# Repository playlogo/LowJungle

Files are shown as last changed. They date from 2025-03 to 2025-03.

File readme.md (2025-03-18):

# LowJungle

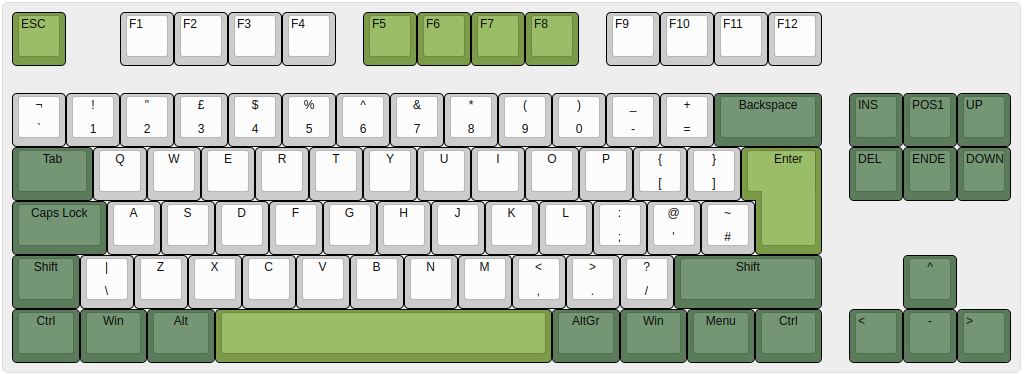
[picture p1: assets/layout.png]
Layout

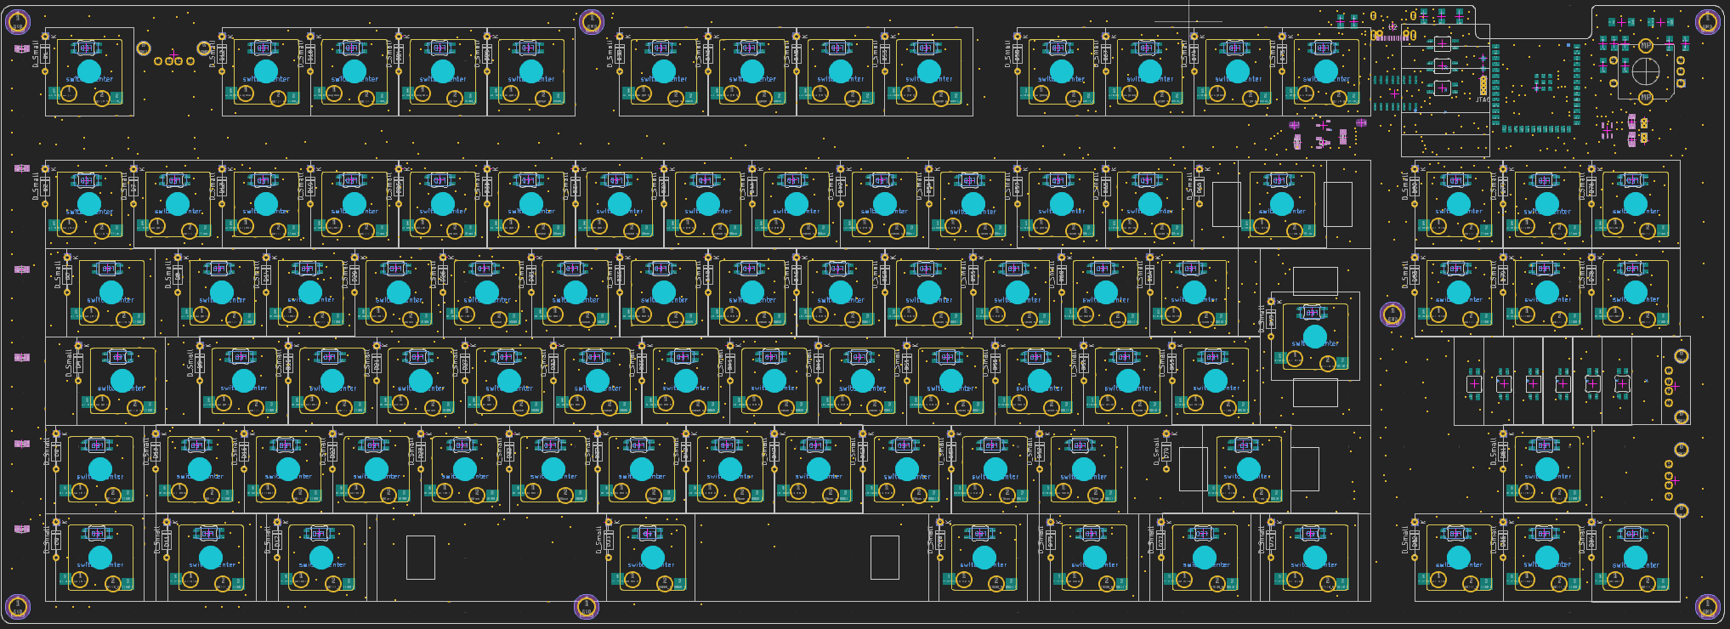
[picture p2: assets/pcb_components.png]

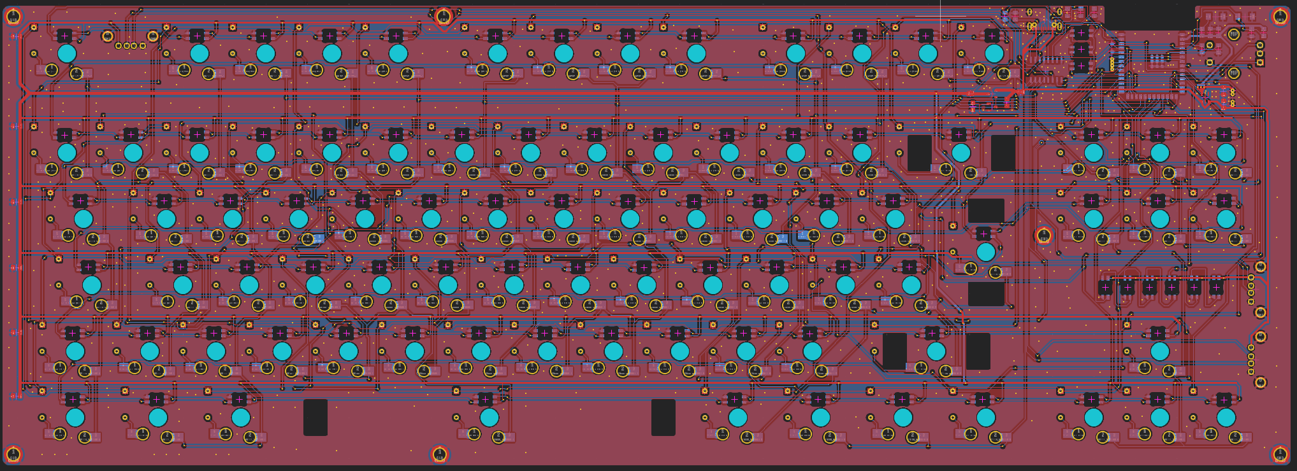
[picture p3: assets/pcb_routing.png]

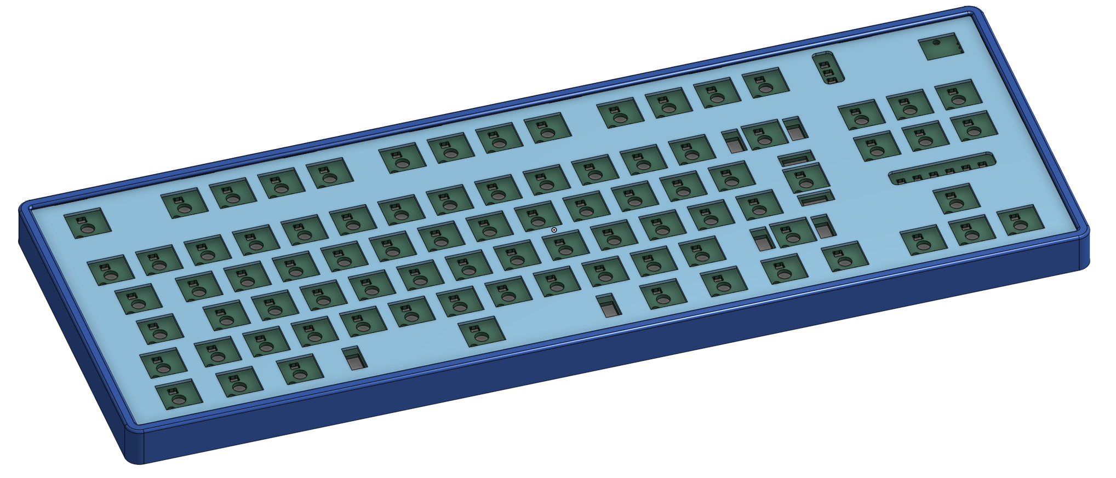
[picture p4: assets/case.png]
Case


A low profile, ~65% keyboard, with:

- Hot swappable sockets
- Per key RGB backlight
- Wifi & BLE (but no battery)
- Integrated 3 port USB Hub

Links:

- [Onshape: Case](https://cad.onshape.com/documents/196ae99135554e28081e9cd8/w/09114671e2d692aadc408c6f/e/86be969bd7a114ceaf756b4a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)
- [Keyboard Layout Editor: Layout](https://www.keyboard-layout-editor.com/#/gists/81105ca4efea79bf3cdf03d682872e17)

## Firmware

For testing: KMK  
For production: QMK

> Circuitpython is soooo much nicer for finding errors in the hardware  
> Status KMK: Pins are correct, keymap is WIP

## PCB

- [Schematic](assets/schematic.pdf)
- No relevant ERC & DRC errors
- Size: 371.48mm x 133.35mm
- VCC for backlight LEDs can be controlled by the ESP32 using 2 mosfets
- Used libraries:
  - [Marbastlib, needs to be installed as plugin](https://github.com/ebastler/marbastlib/tree/main)
  - [easyeda2kicad, needs to be installed separately, used for downloading LCSC schematics & footprints](https://github.com/uPesy/easyeda2kicad.py)
    - Download `C2913204, C192893, C2891732, C778164, C2988369, C8547, C503996, C82942` using `easyeda2kicad --full --lcsc_id=<id>` (one-by-one, yes...)
  - `0_Custom`, included in the `libraries` folder, should load automatically

## Fabrication

> I'm print all parts myself using [the large scale 3D printer (Billig)](https://github.com/playlogo/billig) I'm build for [infill](https://github.com/hackclub/infill).

> Download the latest revision from [Onshape](https://cad.onshape.com/documents/196ae99135554e28081e9cd8/w/09114671e2d692aadc408c6f/e/86be969bd7a114ceaf756b4a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). STLs included with this repo are only meant as a backup if the onshape link ever stops working.

- Largest part: 380mmx145mm
- Recommended settings:
  - 6 wall loops
  - 6 solid top & bottom layers
  - 40% infill
- Notes:
  - `LowJungle-Backplate-V2.stl`: Should be solid
  - `LowJungle-Bumper-Bottom-V2.stl`: Print with TPU, 3x
  - `LowJungle-Bumper-Top-V2.stl`: 4x
  - `LowJungle-Frame-V2.stl`: Manually place tree supports for the USB connector cutouts

## BOM

**PCB:** [$36.34 at JLCPCB](assets/jlcpcb.png)

**Switches:** [Aliexpress: Gateron KS33 low-profile red, 90 for $38.63 => 0.43 per switch](https://de.aliexpress.com/item/1005007794069535.html)

**Keycaps:** [Aliexpress: Low profile set, 143 lily version, $21.61](https://de.aliexpress.com/item/1005004882406296.html)

**Stabilizers:** [Aliexpress: Gateron low-profile stabilizer set, 4x 2u 1x 6.25u, $13.79](https://de.aliexpress.com/item/1005005296240590.html)

**Fasteners:**

| Name | Price | Link |
|---|---|---|
| 30x M2.5x3x3.5mm Heat insert | $1.83 | [Aliexpress](https://de.aliexpress.com/item/1005003582355741.html) |
| 14x M2.5x6mm Hex socket screw (for feet) | $1.41 | [Aliexpress](https://de.aliexpress.com/item/32810872544.html)|
| 16x M2.5x8mm Hex socket screw (for mounting frame) | $1.64 | [Aliexpress](https://de.aliexpress.com/item/32810872544.html) |
| 9x M3x10mm Hex socket screw | $1.79 | [Aliexpress](https://de.aliexpress.com/item/32810872544.html) |

Total: $6,67

**MCU:**

> Note: The ESP32S3 implementation is the same as in my [Hackpad](https://github.com/hackclub/hackpad/pull/570). Thus the cost can be drastically reduced when combining both LCSC orders:
>
> - -$3: Removed handling fee
> - -$6: Random shipping coupon
> - and often times the MOQ from hackpad also covers this project

|Name|Price|Link| Needed if combined order ? |
|----|-----|----|---|
|Espressif Systems ESP32-S3-WROOM-1-N8R2| $4.41| [LCSC](https://www.lcsc.com/product-detail/WiFi-Modules_Espressif-Systems-ESP32-S3-WROOM-1-N8R2_C2913204.html)| Yes|
| N-Channel mosfet | $0.6 for MOQ | [LCSC](https://www.lcsc.com/product-detail/MOSFETs_YONGYUTAI-SI2302_C2891732.html)| Yes |
|3.3V LDO | $0.48 for MOQ| [LCSC](https://www.lcsc.com/product-detail/Voltage-Regulators-Linear-Low-Drop-Out-LDO-Regulators_MICRONE-Nanjing-Micro-One-Elec-ME6211C33M5G-N_C82942.html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)| No |
| USB-A female| $0.42 for MOQ | [LCSC](https://www.lcsc.com/product-detail/USB-Connectors_Shenzhen-Kinghelm-Elec-KH-AF90DIP-112_C503996.html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)|No |
| USB-C female| $0.4 for MOQ | [LCSC](https://www.lcsc.com/product-detail/USB-Connectors_G-Switch-GT-USB-7010ASV_C2988369.html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)|No |
| P-Channel mosfet | $0.49 for MOQ | [LCSC](https://www.lcsc.com/product-detail/MOSFETs_Jiangsu-Changjing-Electronics-Technology-Co-Ltd-CJ2301-S1_C8547.html)|No |
| Mini push button | $0.47 for MOQ | [LCSC](https://www.lcsc.com/product-detail/Tactile-Switches_G-Switch-GT-TC029A-H020-L1N_C778164.html?s_z=n_SKRKAEE020)|No |
| CoreChips SL2.1A USB Hub driver | $1.32 for MOQ | [LCSC](https://www.lcsc.com/product-detail/USB-HUB-Controllers_CoreChips-SL2-1A_C192893.html?s_z=n_C192893)|No |
|---|----|---|---|
| 1N4148 Diodes | $1.04 for 100 | [LCSC](https://www.lcsc.com/product-detail/Switching-Diodes_LangJie-1N4148_C18195411.html?s_z=n_1N4148%2520Diodes) | Yes |
|10uF 0805 Capacitor | $0.16 for MOQ| [LCSC](https://www.lcsc.com/product-detail/Multilayer-Ceramic-Capacitors-MLCC-SMD-SMT_Samsung-Electro-Mechanics-CL21A106KOQNNNE_C1713.html)| No|
| 100nF * | $0.3 for MOQ | [LCSC](https://www.lcsc.com/product-detail/Multilayer-Ceramic-Capacitors-MLCC-SMD-SMT_FH-Guangdong-Fenghua-Advanced-Tech-0805B104J500NT_C29926.html)|No|
| 1uF * | $1 for MOQ | [LCSC](https://www.lcsc.com/product-detail/Multilayer-Ceramic-Capacitors-MLCC-SMD-SMT_YAGEO-CC0805JKX7R9BB105_C541528.html) | No |
|10k 0805 Resistor | $0.13 for MOQ | [LCSC](https://www.lcsc.com/product-detail/Chip-Resistor-Surface-Mount_VO-SCR0805J10K_C5140188.html?s_z=n_resistor)| No|
| 5.1k * | $0.15 for MOQ | [LCSC](https://www.lcsc.com/product-detail/Chip-Resistor-Surface-Mount_UNI-ROYAL-Uniroyal-Elec-0805W8J0512T5E_C26023.html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) | No |
| 100k * |  $0.13 for MOQ | [LCSC](https://www.lcsc.com/product-detail/Chip-Resistor-Surface-Mount_VO-SCR0805J100K_C3017875.html?s_z=n_resistor) | No |

Total (without combined order): $11.46  
Total (with combined order): $6.01

>Note: Combined LCSC order will be around ~$28 (including shipping) for both hackpad and hackboard

**Misc Electronics:**

|Name|Price|Link|
| ----- | ---- | ---- |
| SK6812 MINI-E | $2.85 for 100 | [Aliexpress](https://de.aliexpress.com/item/1005002782417198.html) |
| Gateron Low-profile hot-swap socket | $9.03 for 100 => $0.1 per socket | [Aliexpress](https://de.aliexpress.com/item/1005008078611488.html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) |
| Rotary-encoder | in stock | - |

Total: $11.88

**Other parts:**

|Name|Reason|Price|Link|
|----|---|-----|----|
| Poron foam, Bottom case <-> PCB, 2.5mm 15x35cm | Sound damping | $6.10 | [Aliexpress](https://de.aliexpress.com/item/1005007442653383.html)|
| EVA foam, PCB <-> Top plate , 1mm 35x50cm | Stability of top plate |  $2.05 | [Aliexpress](https://de.aliexpress.com/item/1005002856054113.html)|
|EVA foam, PCB <-> Keyswitch  | Sound damping | $3.42 | [Aliexpress](https://de.aliexpress.com/item/1005005556269716.html)|
|PE foam, Top plate <-> Keyswitch | Water spill protection (has happened before) | $2.19 | [Aliexpress](https://de.aliexpress.com/item/1005004804230184.html)|

Total: $13,76

### BOM total

**Fasteners:** $6,67
**PCB:** $36.34  
**Switches:** $38.63  
**Keycaps:** $21.61  
**Stabilizers:** $13.79  
**MCU:** $6.01  
**Misc Electronics:** $11.88  
**Other parts:** $13,76

**Total:** $148,69

> Note: Aliexpress prices are only valid until 26. March (15. anniversary sale)
> => If the grant is issued after 24. March, it would be awesome to have ~$15 buffer for changed prices. The unused amount would be returned to HackClub.

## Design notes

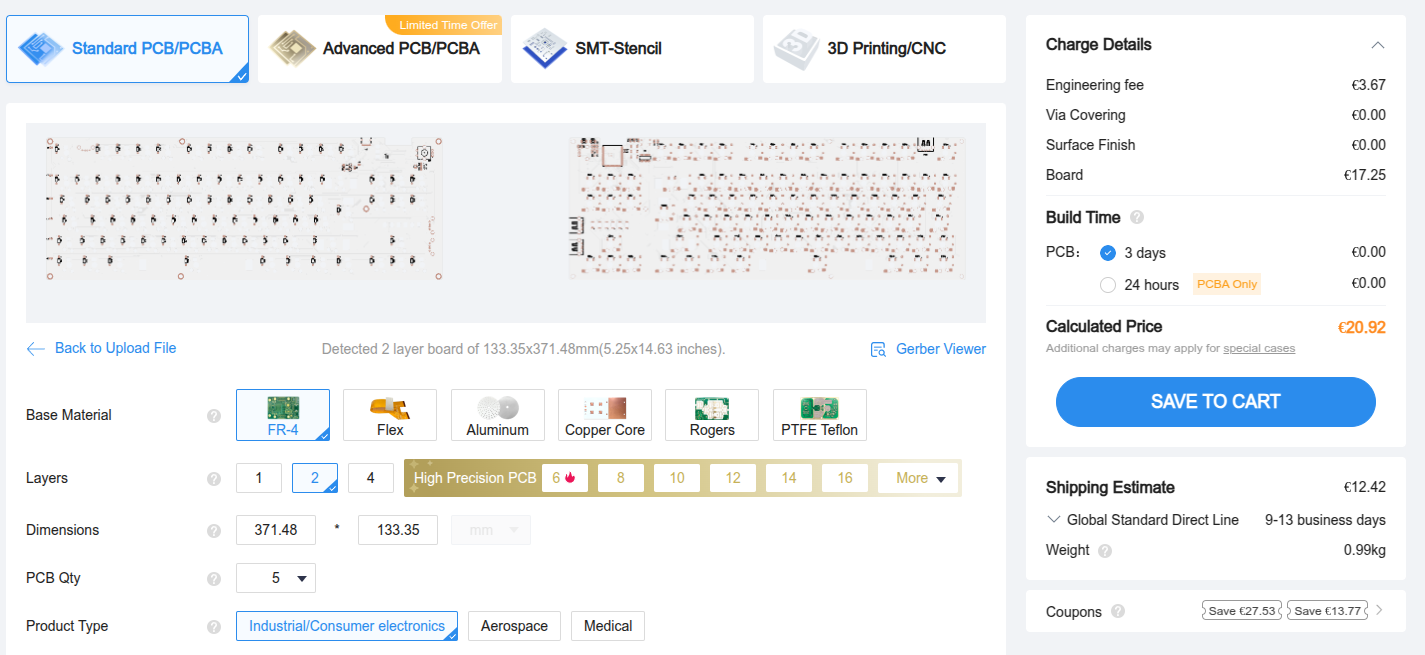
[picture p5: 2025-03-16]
assets/jlcpcb.png

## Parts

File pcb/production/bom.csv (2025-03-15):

Designator | Footprint | Quantity | Value | LCSC Part #
C1, C12, C13, C14, C2, C3, C4, C5, C6, C8 | 0805 | 10 | 10uF
C10, C11, C7 | 0805 | 3 | 100nF
C15, C16, C9 | 0805 | 3 | 1uF
CH1, CH10, CH12, CH13, CH14, CH15, CH16, CH18, CH19, CH2, CH20, CH21, CH22, CH24, CH25, CH26, CH27, CH28, CH29, CH30, CH31, CH32, CH33, CH34, CH35, CH36, CH37, CH38, CH39, CH40, CH41, CH42, CH43, CH44, CH45, CH46, CH47, CH48, CH49, CH50, CH51, CH52, CH53, CH54, CH55, CH56, CH57, CH58, CH59, CH60, CH61, CH62, CH63, CH64, CH65, CH67, CH7, CH74, CH75, CH76, CH77, CH78, CH79, CH8, CH80, CH81, CH82, CH83, CH84, CH85, CH9 | SW_KS33_HS_KS-2P02B01-02_1u | 71 | KS33_SW_HS
CH11, CH17, CH5, CH6, CH66, CH71, CH72, CH73 | SW_KS33_HS_KS-2P02B01-02_1.25u | 8 | KS33_SW_HS
CH23 | SW_KS33_HS_KS-2P02B01-02_6.25 | 1 | KS33_SW_HS
CH3 | SW_KS33_HS_KS-2P02B01-02_1.5u | 1 | KS33_SW_HS
CH4 | SW_KS33_HS_KS-2P02B01-02_1.75u | 1 | KS33_SW_HS
CH68 | SW_KS33_HS_KS-2P02B01-02_2u | 1 | KS33_SW_HS
CH69 | SW_KS33_HS_KS-2P02B01-02_Enter | 1 | KS33_SW_HS
CH70 | SW_KS33_HS_KS-2P02B01-02_2.75u | 1 | KS33_SW_HS
D1, D10, D11, D12, D13, D14, D15, D16, D17, D18, D19, D2, D20, D21, D22, D23, D24, D25, D26, D27, D28, D29, D3, D30, D31, D32, D33, D34, D35, D36, D37, D38, D39, D4, D40, D41, D42, D43, D44, D45, D46, D47, D48, D49, D5, D50, D51, D52, D53, D54, D55, D56, D57, D58, D59, D6, D60, D61, D62, D63, D64, D65, D66, D67, D68, D69, D7, D70, D71, D72, D73, D74, D75, D76, D77, D78, D79, D8, D80, D81, D82, D83, D84, D85, D9 | D_DO-35_SOD27_P7.62mm_Horizontal | 85 | D_Small
J1 | PinHeader_1x04_P1.00mm_Vertical | 1 | JTAG
J2 | PinHeader_1x02_P1.00mm_Vertical | 1 | 3.3V
J3 | PinHeader_1x02_P1.00mm_Vertical | 1 | 5V
LDO1 | SOT-23-5_L3.0-W1.7-P0.95-LS2.8-BL | 1 | ME6211C33M5G-N | C82942
LED1, LED10, LED11, LED12, LED13, LED14, LED15, LED16, LED17, LED18, LED19, LED2, LED20, LED21, LED22, LED23, LED24, LED25, LED26, LED27, LED28, LED29, LED3, LED30, LED31, LED32, LED33, LED34, LED35, LED36, LED37, LED38, LED39, LED4, LED40, LED41, LED42, LED43, LED44, LED45, LED46, LED47, LED48, LED49, LED5, LED50, LED51, LED52, LED53, LED54, LED55, LED56, LED57, LED58, LED59, LED6, LED60, LED61, LED62, LED63, LED64, LED65, LED66, LED67, LED68, LED69, LED7, LED70, LED71, LED72, LED73, LED74, LED75, LED76, LED77, LED78, LED79, LED8, LED80, LED81, LED82, LED83, LED84, LED85, LED86, LED87, LED88, LED89, LED9, LED90, LED91, LED92, LED93, LED94 | LED_KS33_6028R | 94 | KS33_SK6812MINI-E
Q1 | SOT-23-3_L3.0-W1.7-P0.95-LS2.9-BR | 1 | CJ2301 S1 | C8547
Q2 | SOT-23-3_L2.9-W1.3-P1.90-LS2.4-BR | 1 | SI2302_C2891732 | C2891732
R1, R2, R5 | 0805 | 3 | 10k
R3, R4, R6 | 0805 | 3 | 5.1k
SW1 | RotaryEncoder_Alps_EC11E-Switch_Vertical_H20mm_CircularMountingHoles | 1 | RotaryEncoder_Switch
SW2, SW3 | SW-SMD_L3.9-W2.9-LS5.0 | 2 | GT-TC029A-H020-L1N | C778164
TP1 | TestPoint_Pad_D1.0mm | 1 | RX
TP2 | TestPoint_Pad_D1.0mm | 1 | TX
U1 | WIRELM-SMD_ESP32-S3-WROOM-1 | 1 | ESP32-S3-WROOM-1(N8R2) | C2913204
U2 | USB-C-SMD_G-SWITCH_GT-USB-7010ASV | 1 | GT-USB-7010ASV | C2988369
U3 | SOP-16_L10.0-W3.9-P1.27-LS6.0-BL | 1 | SL2.1A | C192893
USB1, USB2 | USB-A-TH_USB-A-F-90 | 2 | KH-AF90DIP-112 | C503996
USB3 | USB-A-TH_USB-A-F-90 | 1 | DNP | C503996

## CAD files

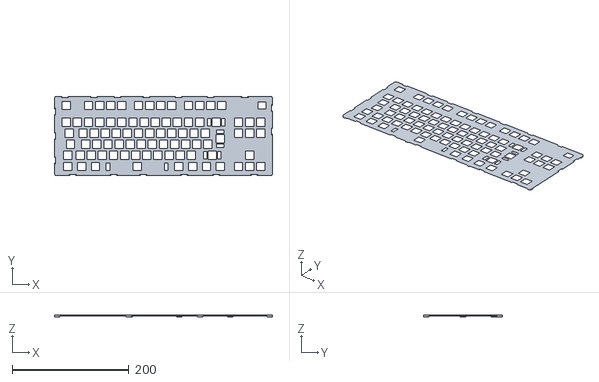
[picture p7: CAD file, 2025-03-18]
case/LowJungle-Backplate-V2.stl
373.9 x 135.8 x 2.59

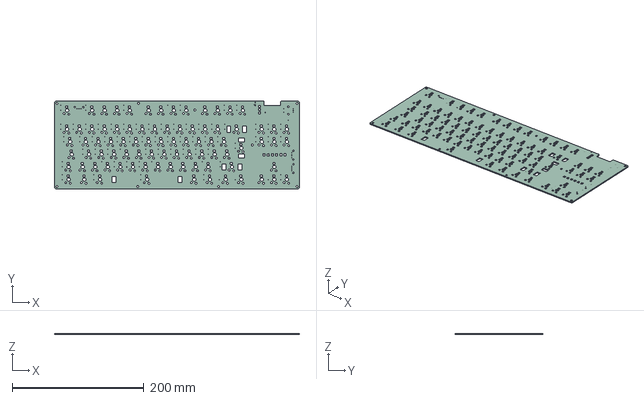
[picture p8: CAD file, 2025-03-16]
pcb/LowJungle.step
371.5 x 133.4 x 1.51 mm
LowJungle_copper
LowJungle_PCB

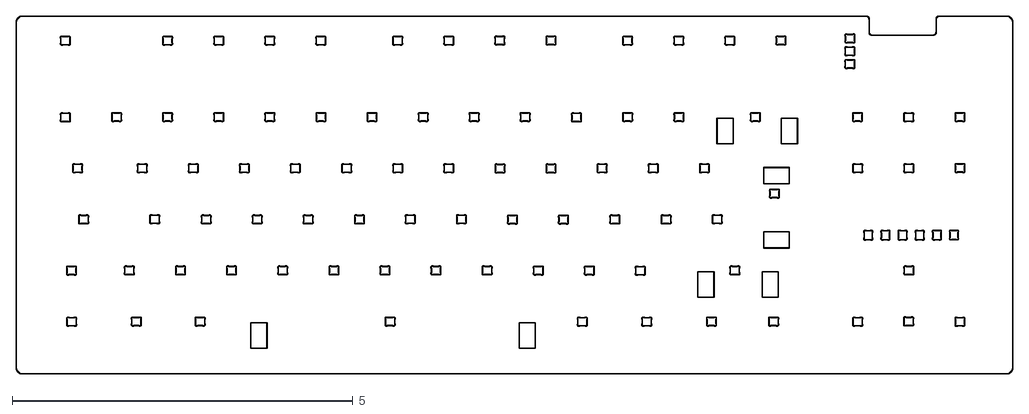
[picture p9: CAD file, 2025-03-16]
pcb/out/LowJungle-Edge_Cuts.dxf
14.6 x 5.25

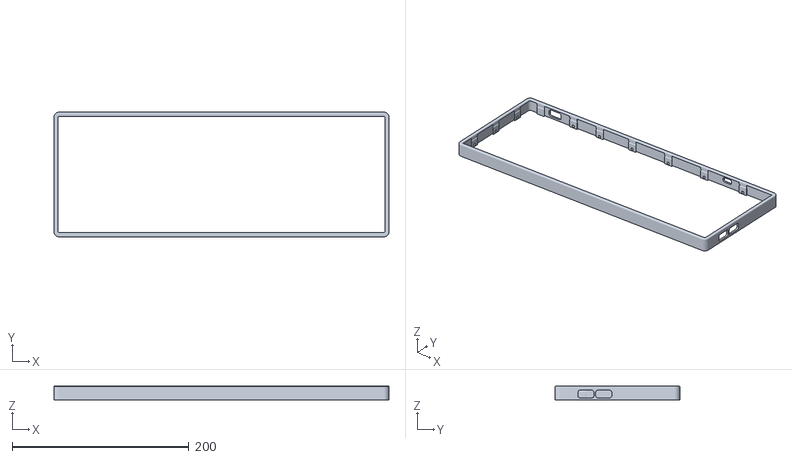
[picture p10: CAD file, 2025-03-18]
case/LowJungle-Frame-V2.stl
379.3 x 141.2 x 16.2

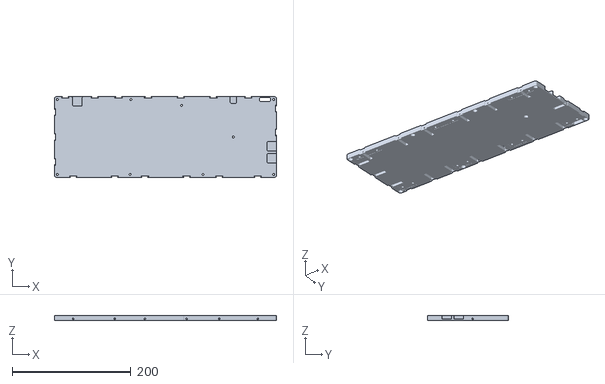
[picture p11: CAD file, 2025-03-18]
case/LowJungle-Bottom-V2.stl
373.9 x 135.8 x 8.00

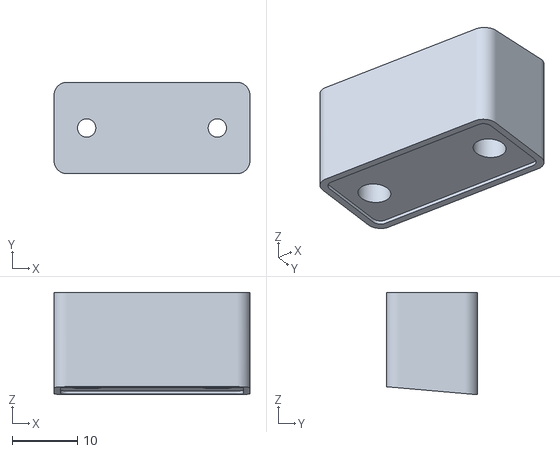
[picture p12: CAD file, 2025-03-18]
case/LowJungle-Bumper-Top-V2.stl
30.0 x 14.0 x 15.7

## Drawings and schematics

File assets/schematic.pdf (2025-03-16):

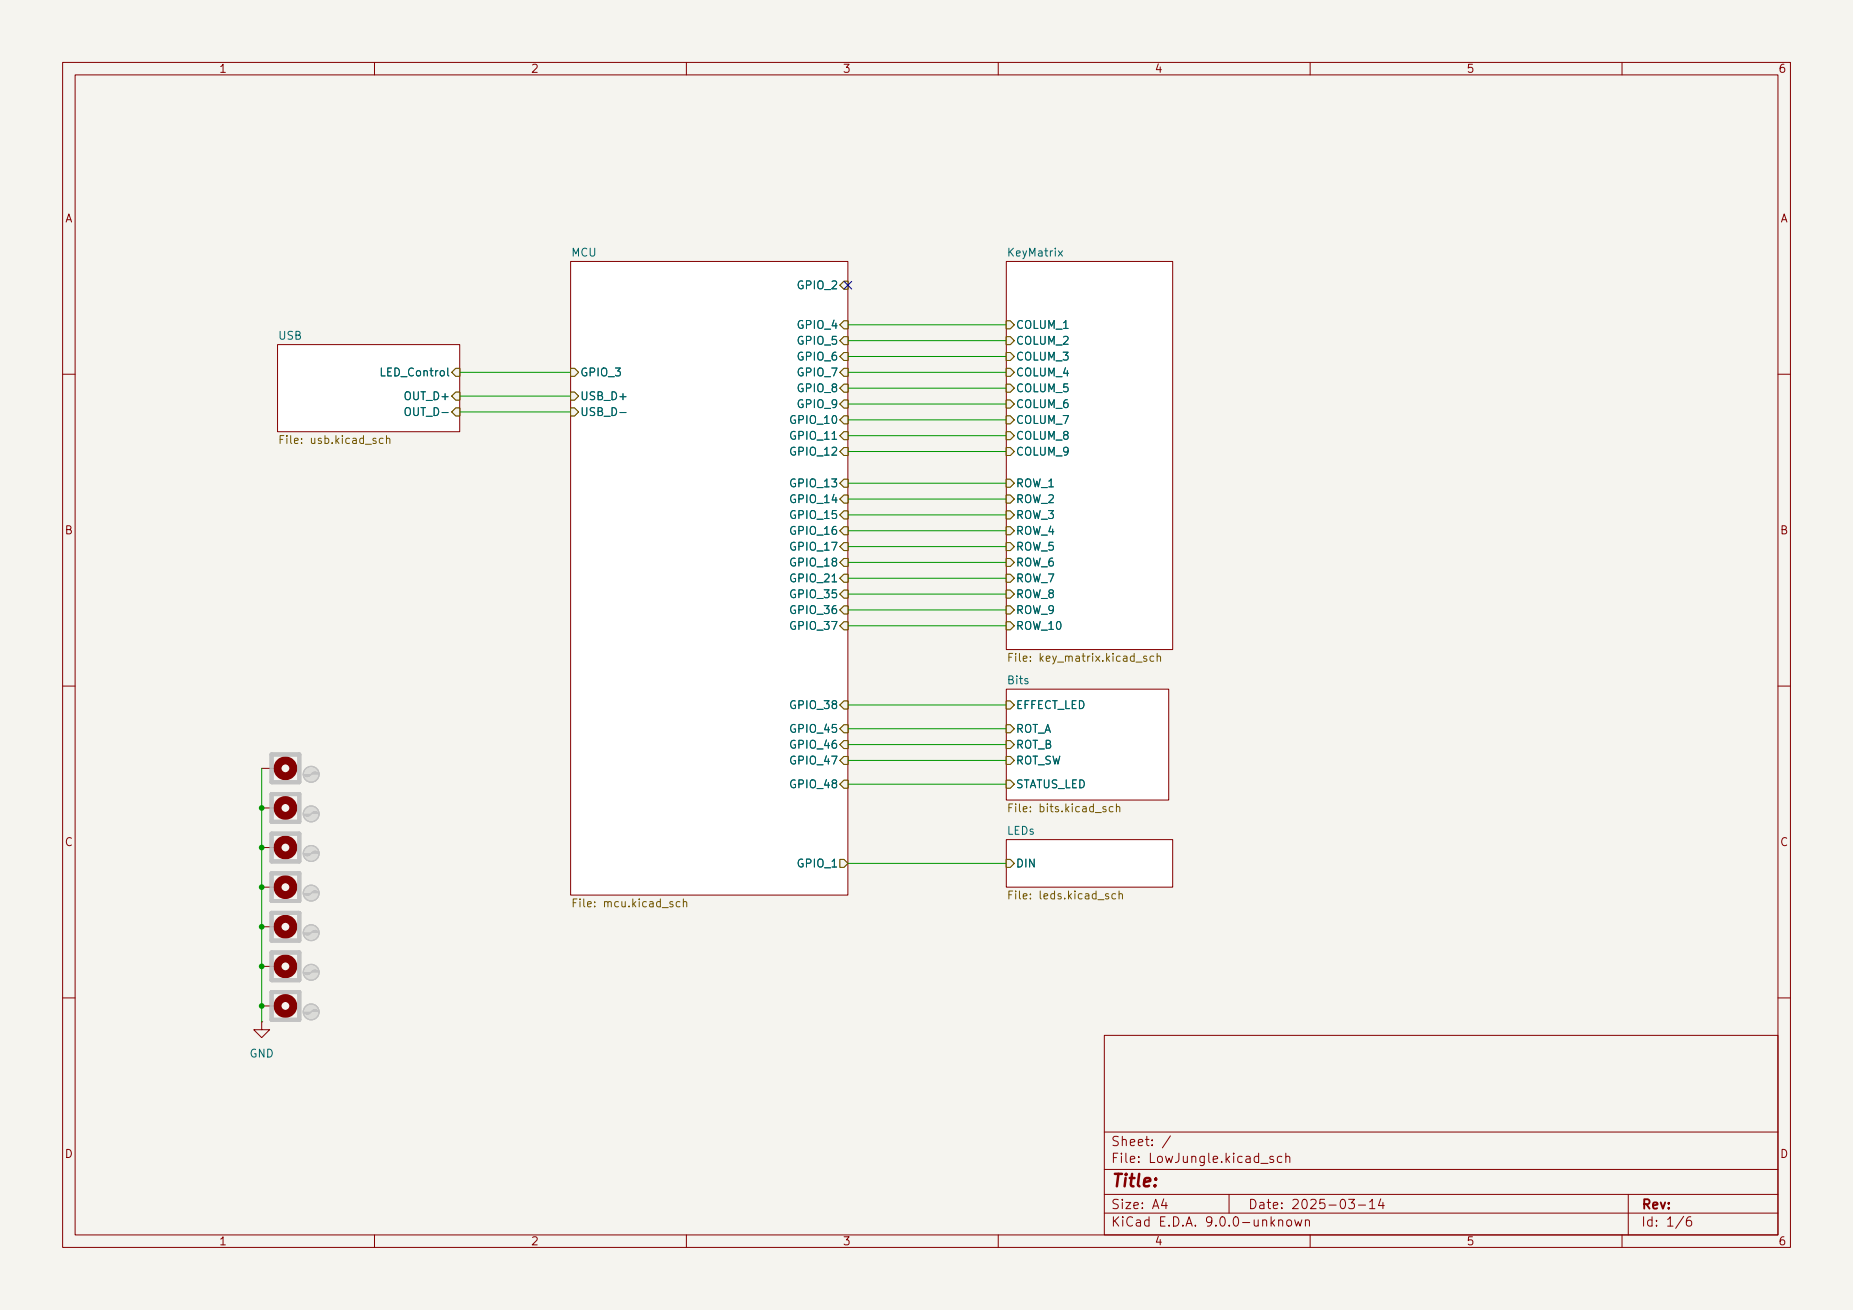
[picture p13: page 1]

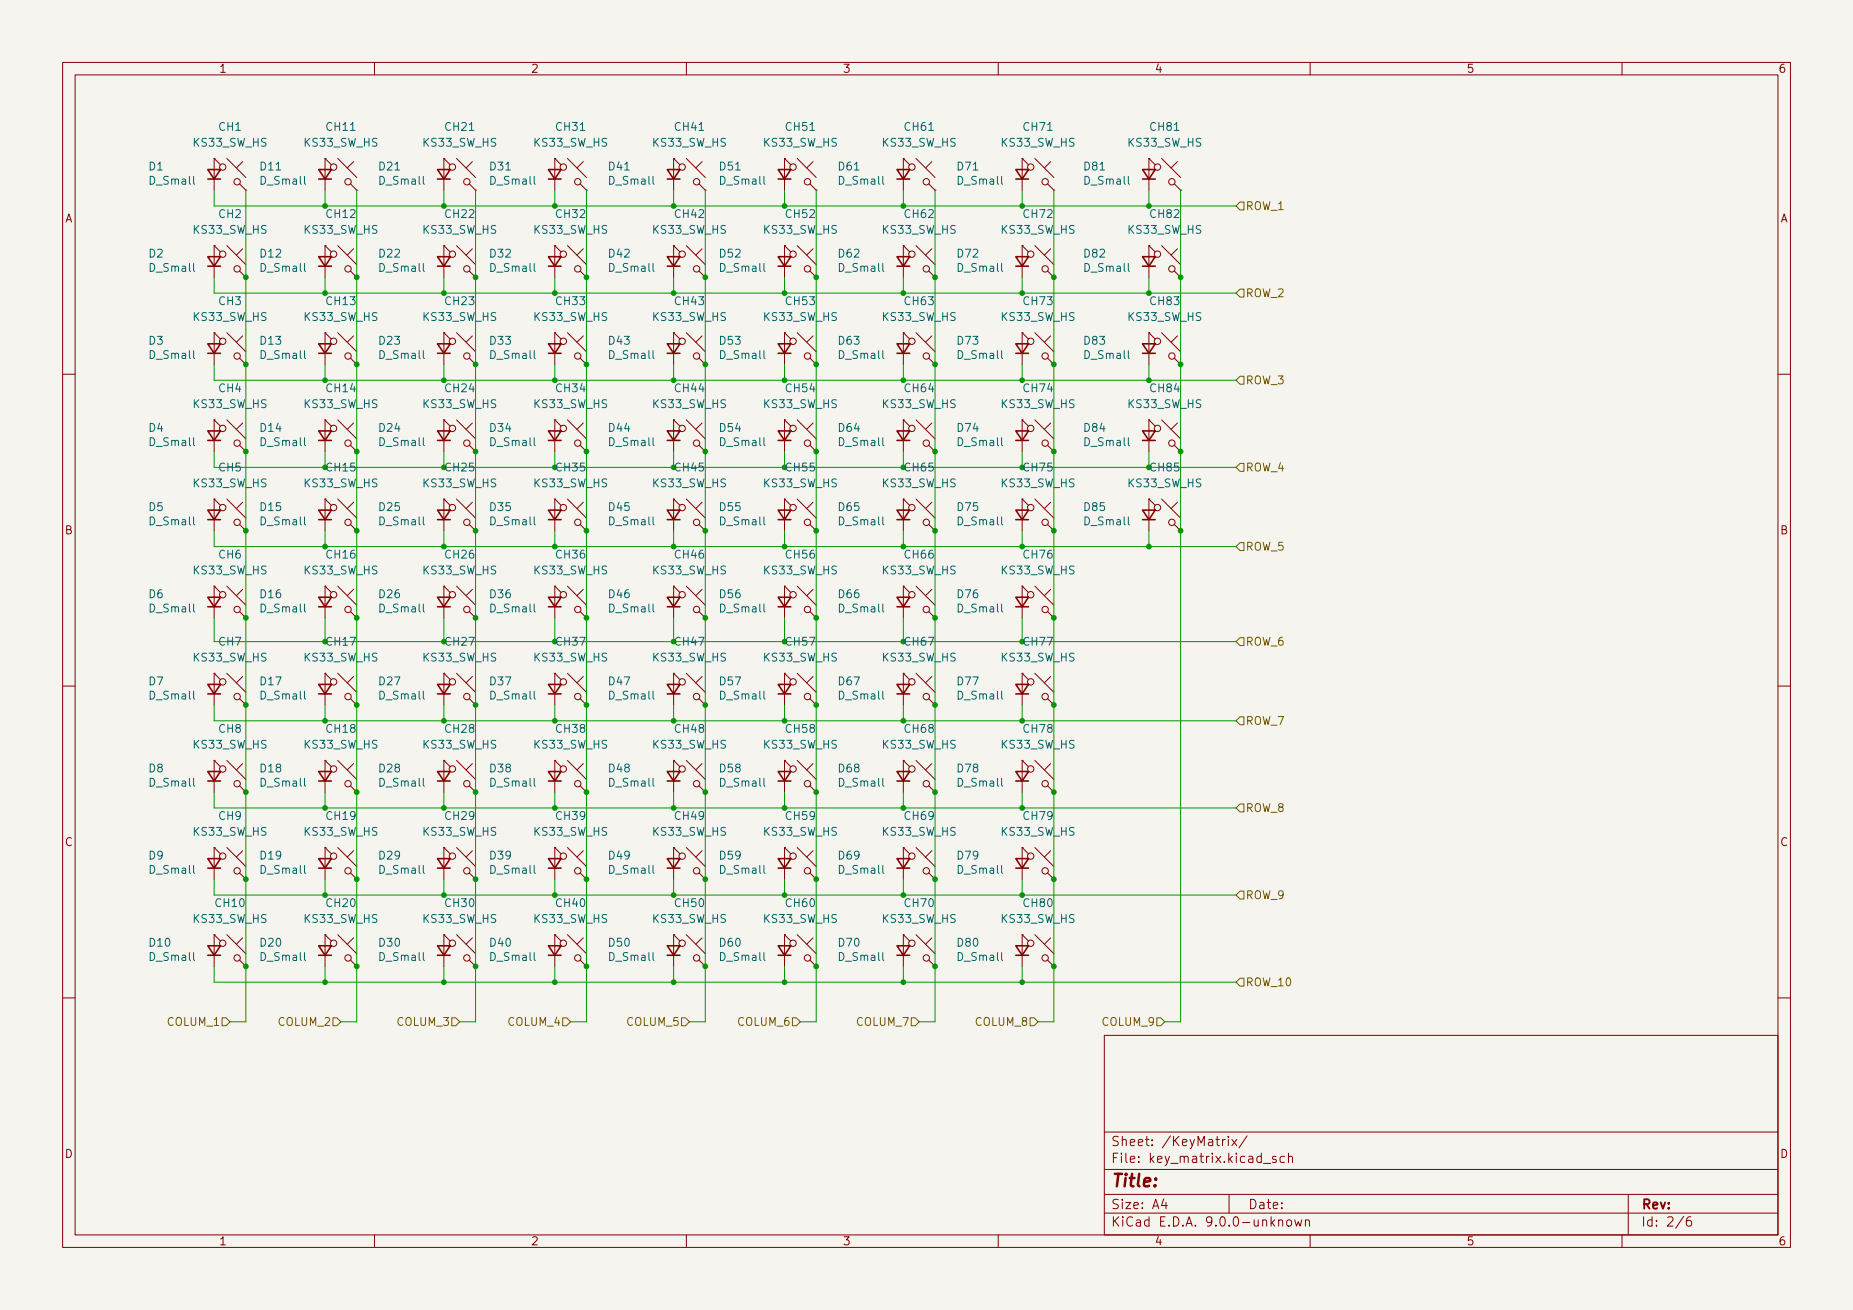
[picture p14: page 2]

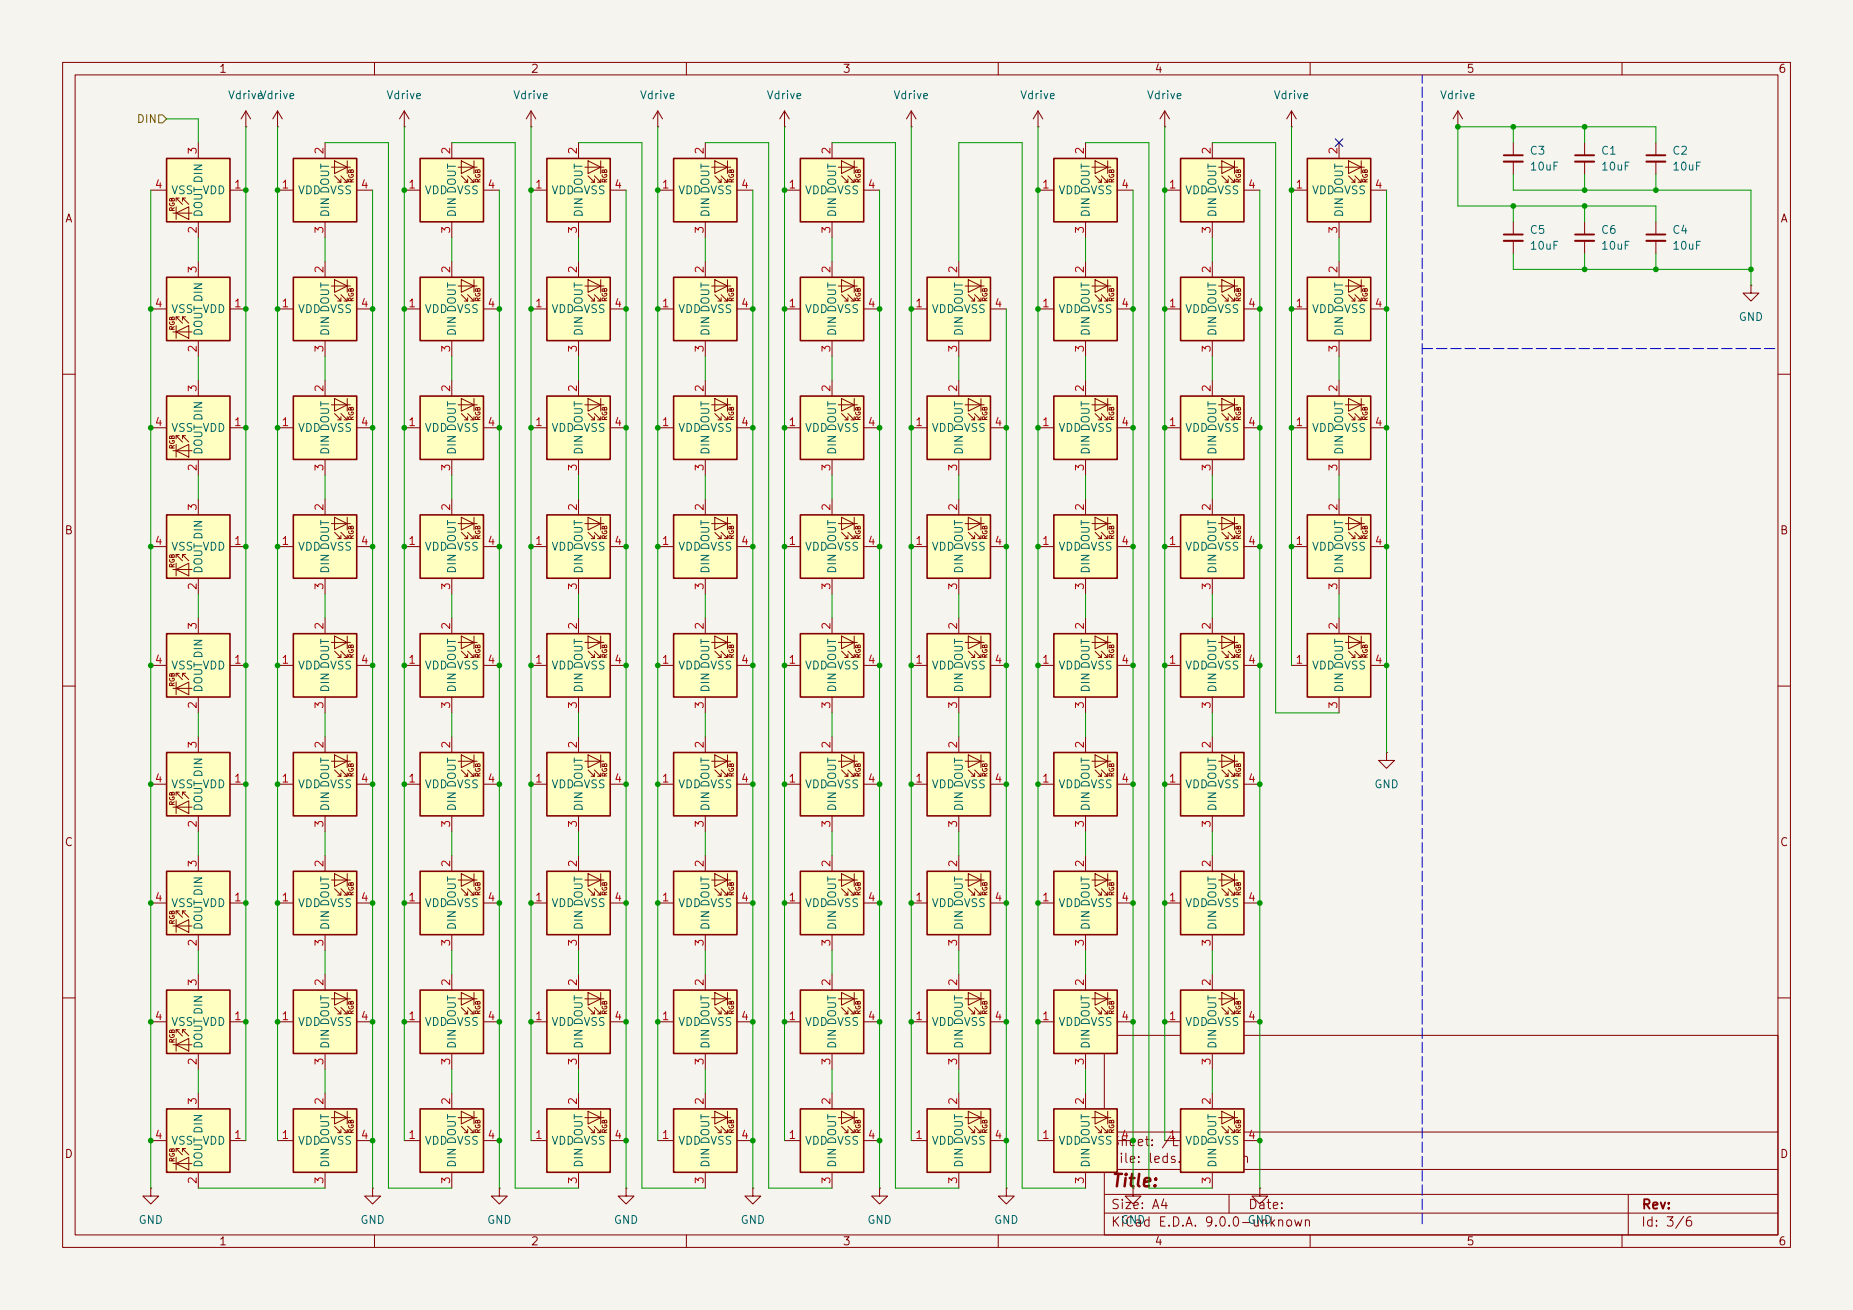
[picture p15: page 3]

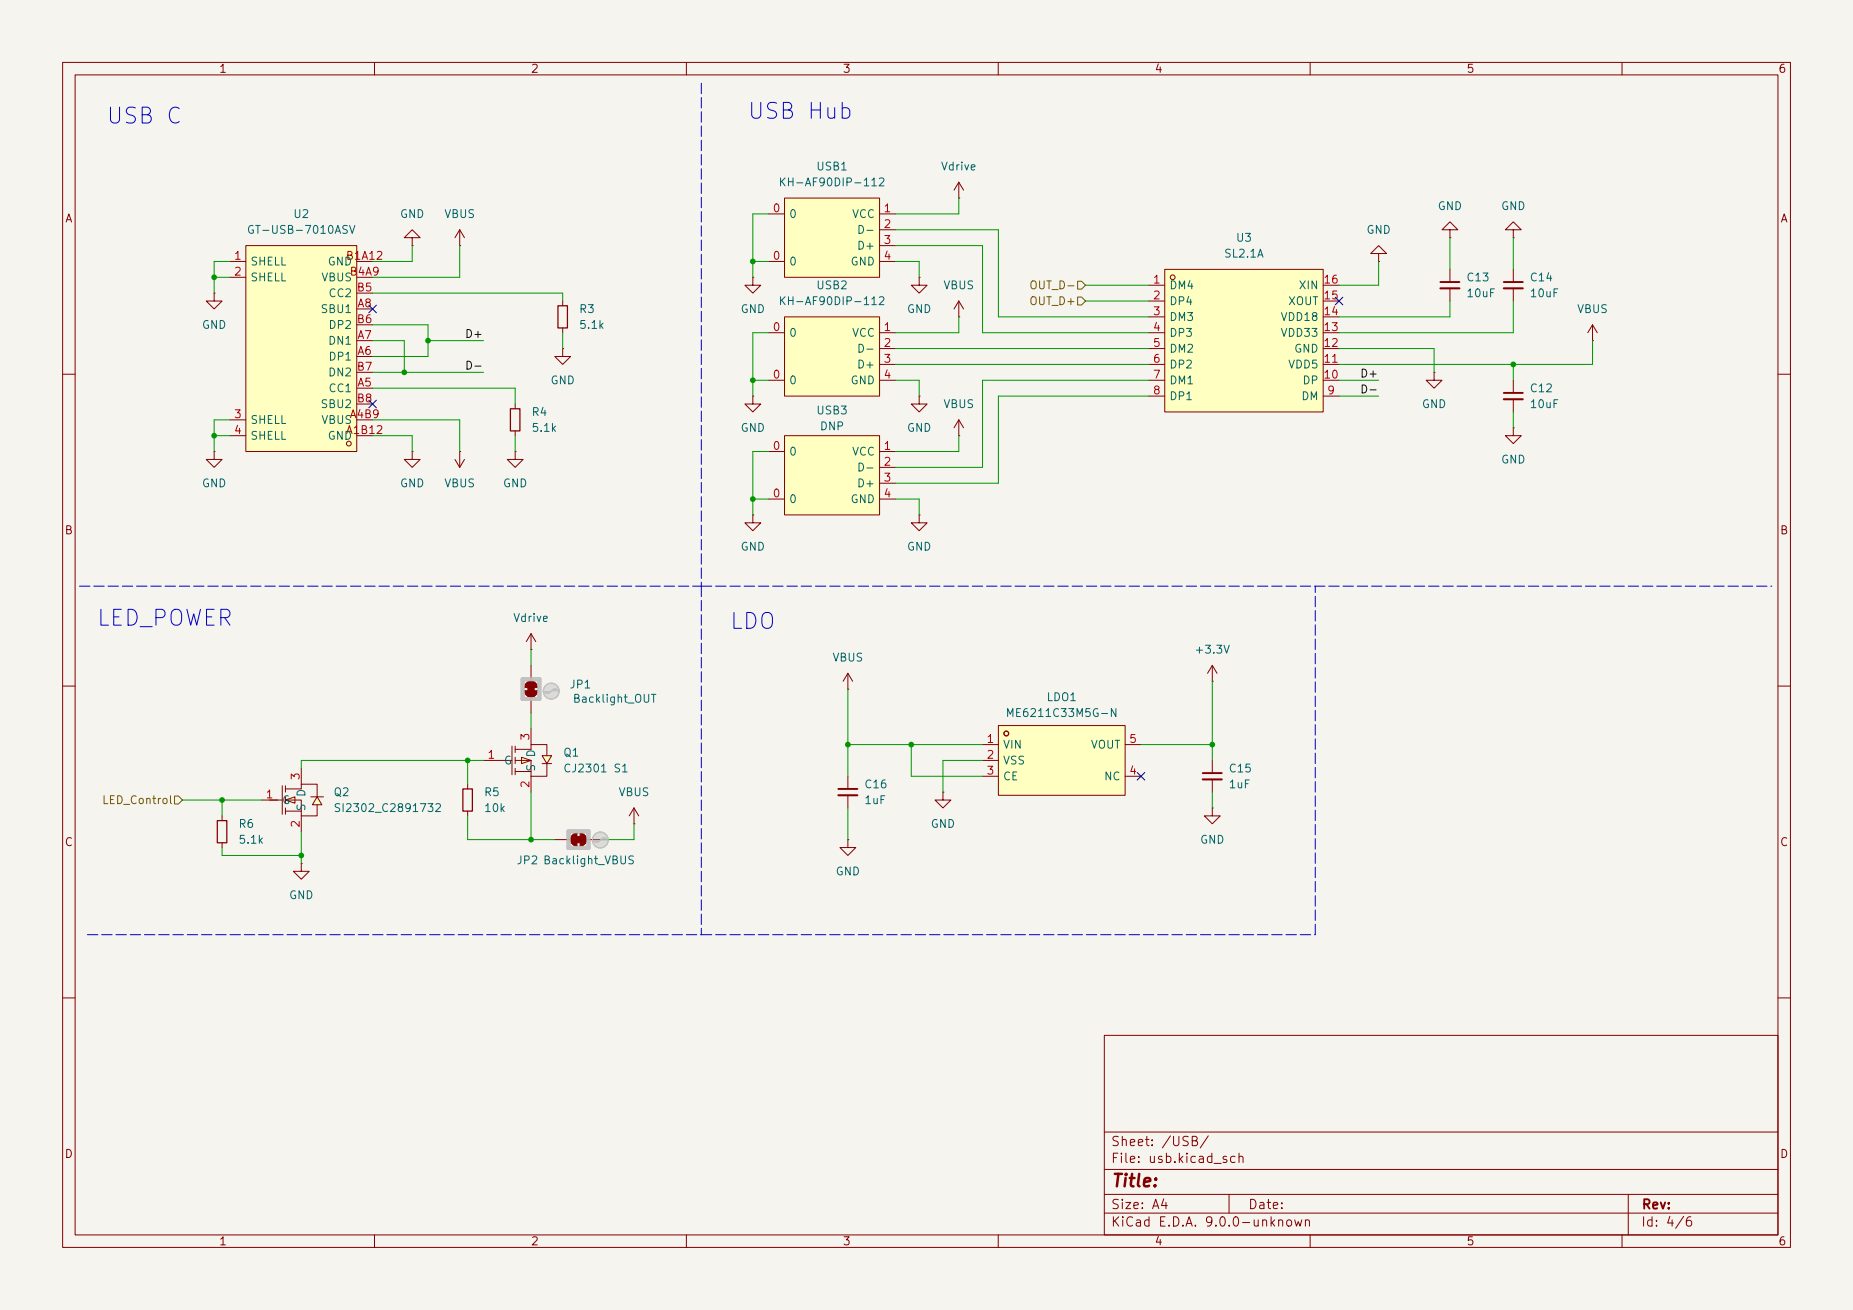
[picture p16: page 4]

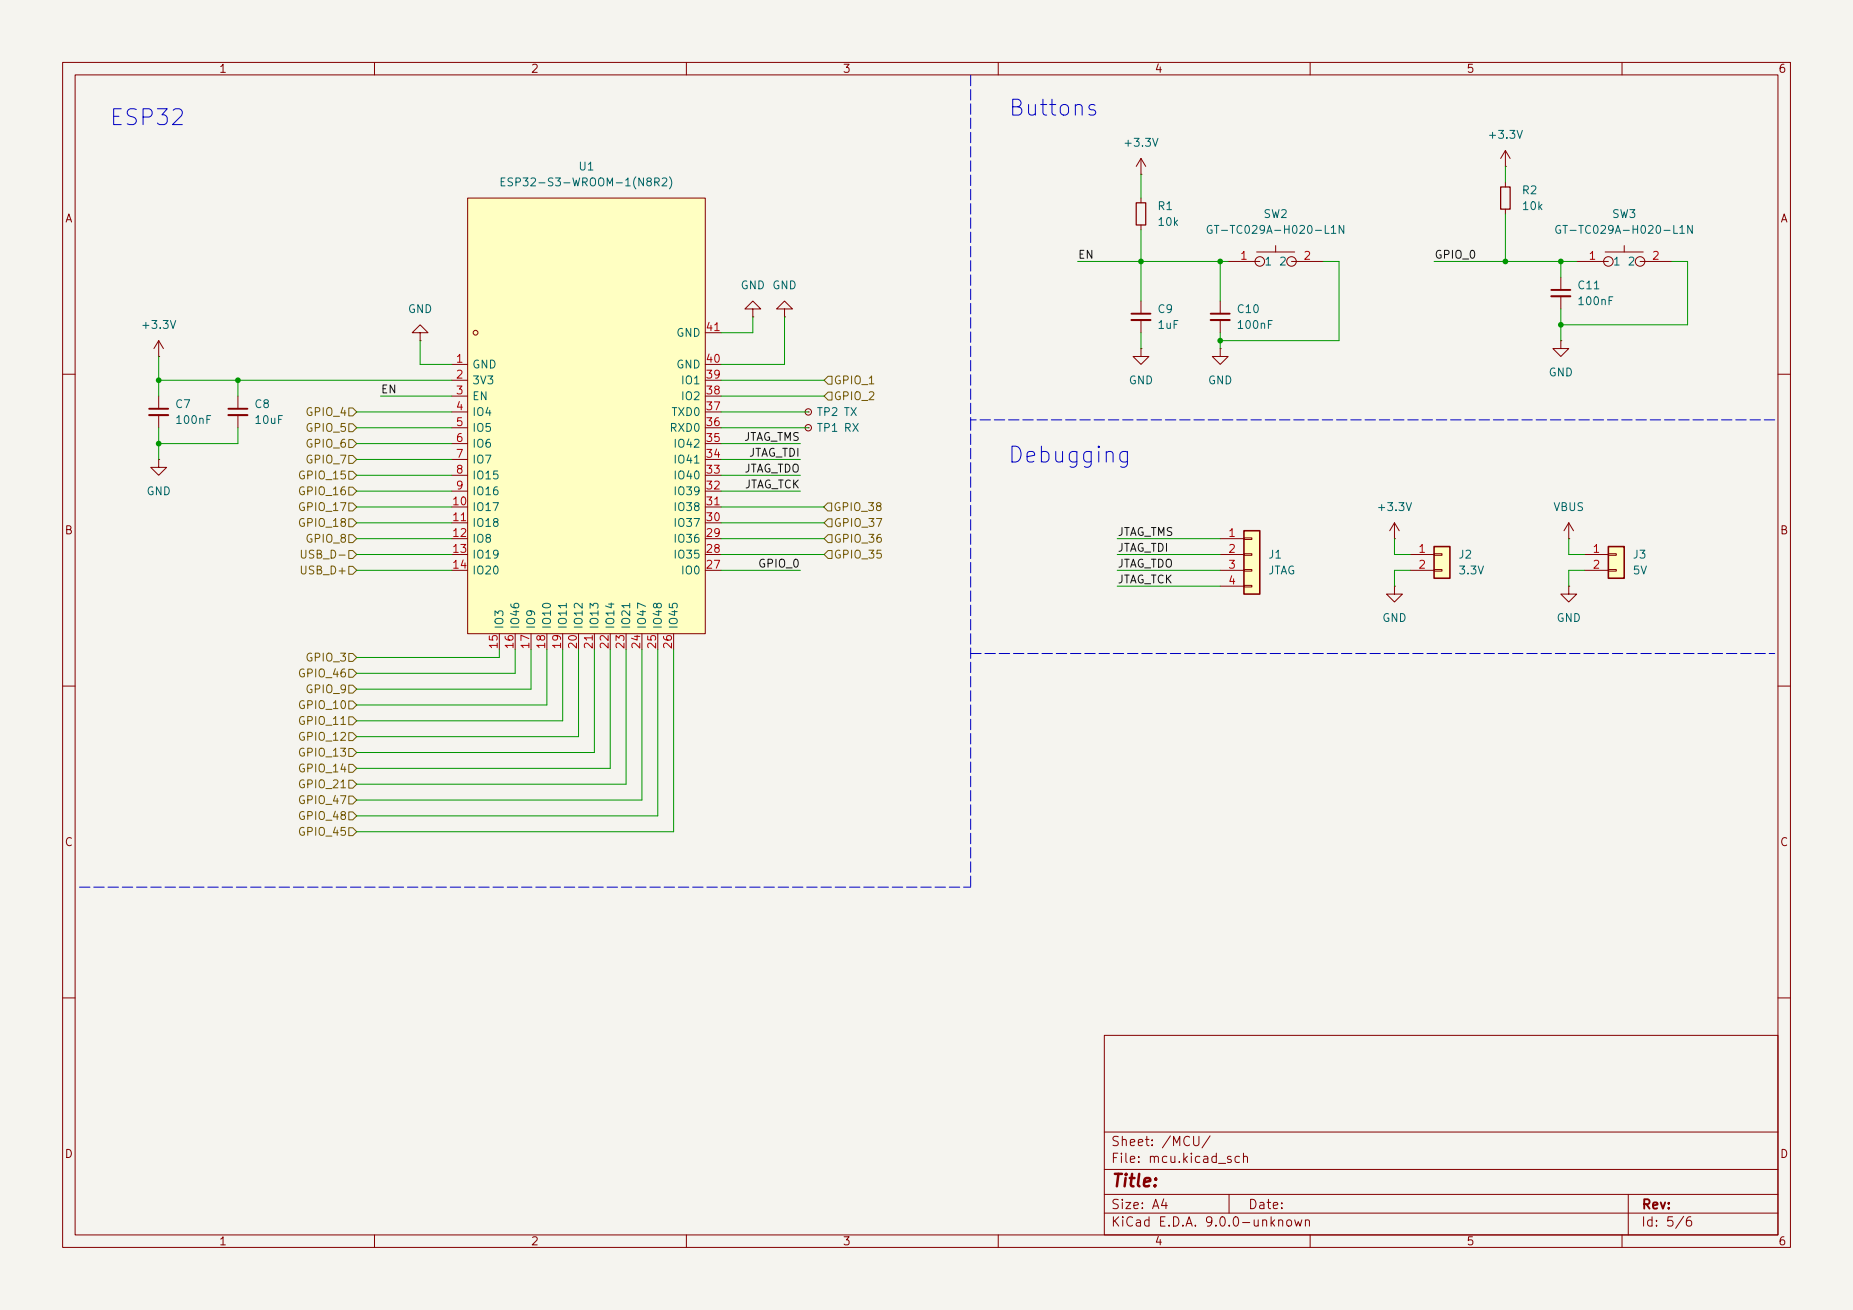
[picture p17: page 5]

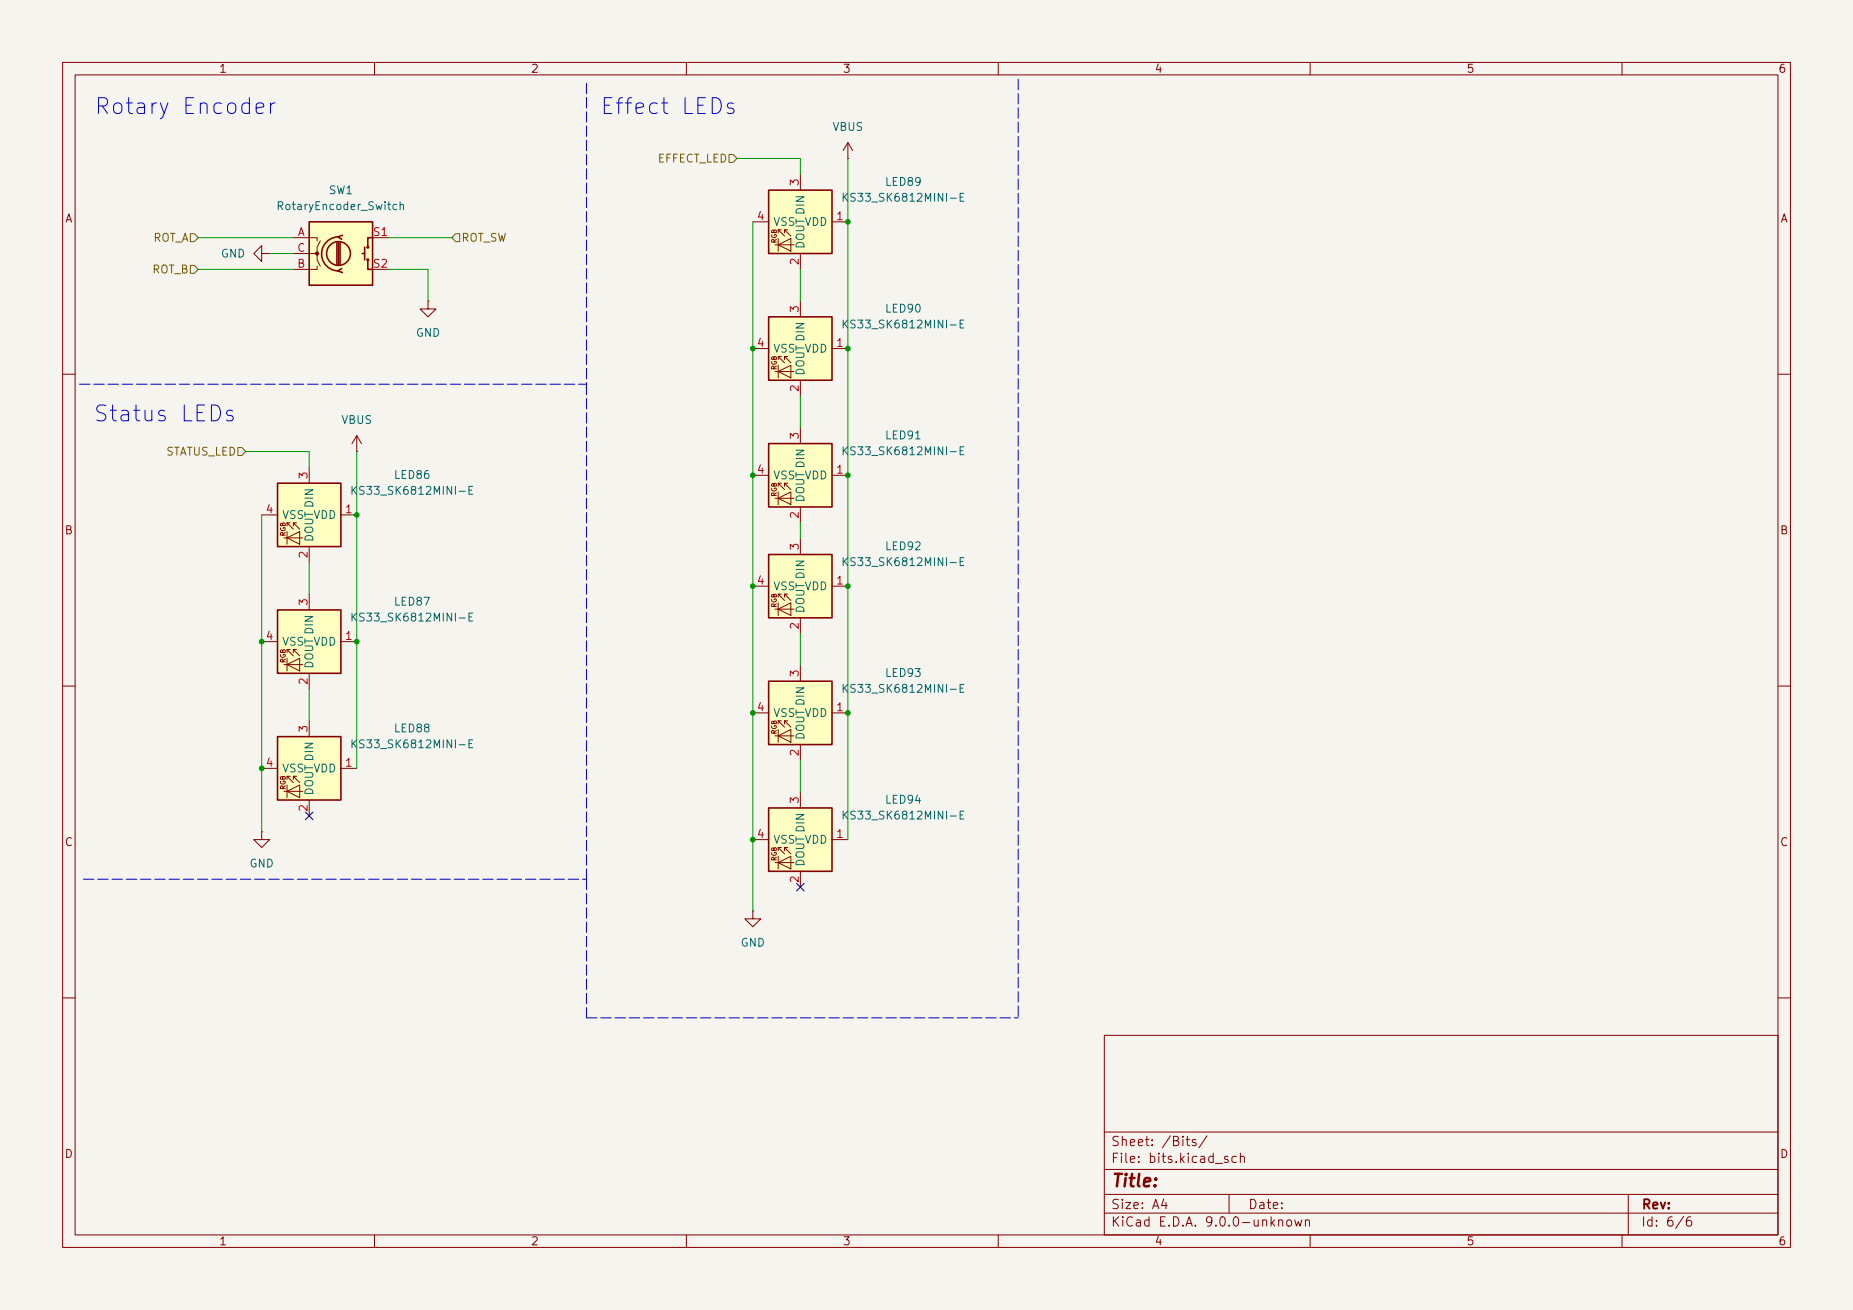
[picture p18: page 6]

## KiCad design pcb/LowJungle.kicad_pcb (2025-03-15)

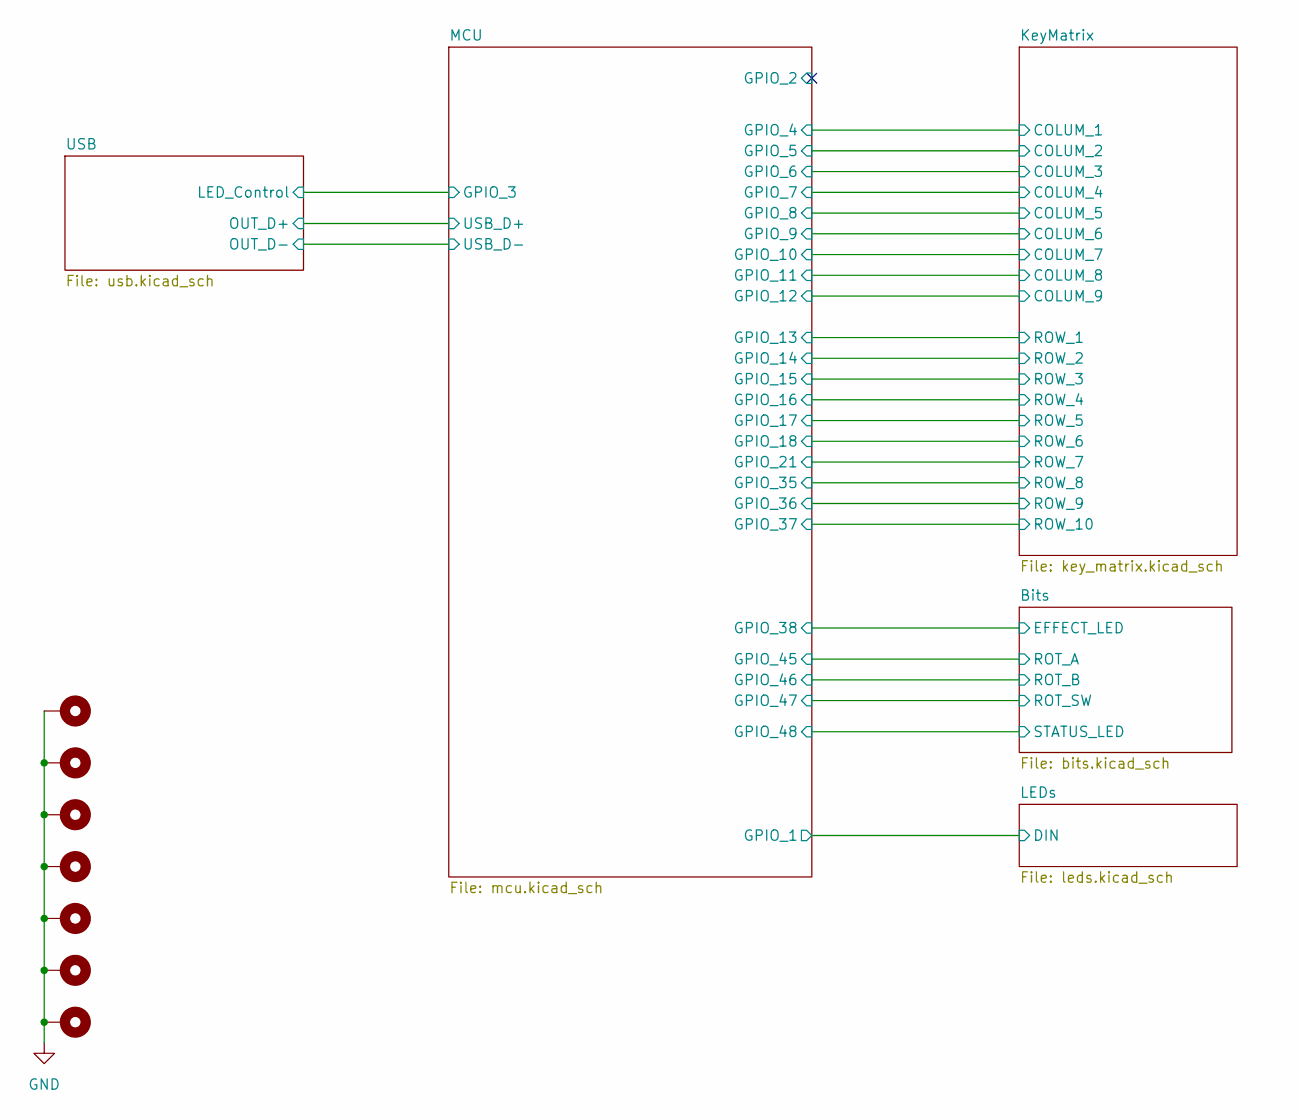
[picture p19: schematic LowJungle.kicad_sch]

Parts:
H1, H2, H3, H4, H5, H6, H7: MountingHole_Pad; MountingHole_3.2mm_M3_DIN965_Pad_TopOnly

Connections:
GND: H1.1, H2.1, H3.1, H4.1, H5.1, H6.1, H7.1; also elsewhere on the board

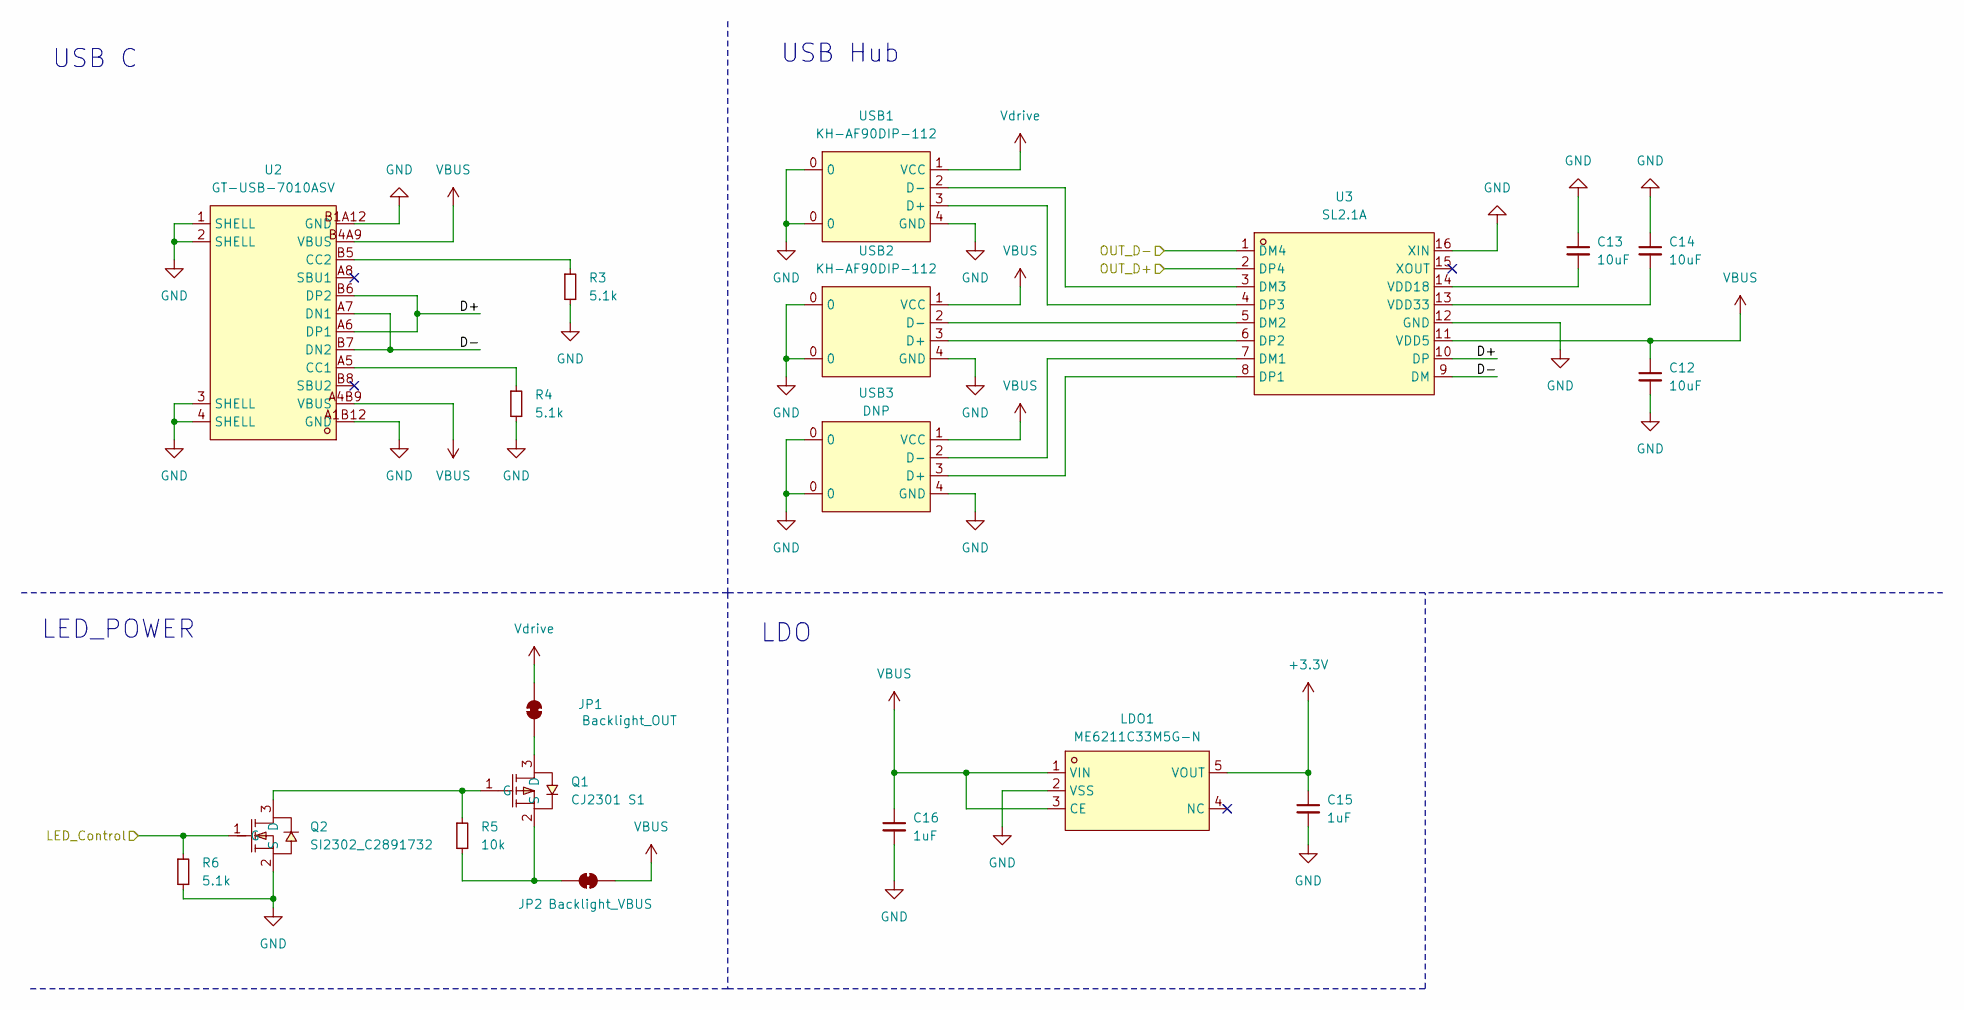
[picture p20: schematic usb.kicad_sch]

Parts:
C12, C13, C14: 10uF; C_0805_2012Metric_Pad1.18x1.45mm_HandSolder
C15, C16: 1uF; C_0805_2012Metric_Pad1.18x1.45mm_HandSolder
JP1: Backlight_OUT; SolderJumper-2_P1.3mm_Bridged2Bar_RoundedPad1.0x1.5mm
JP2: Backlight_VBUS; SolderJumper-2_P1.3mm_Bridged2Bar_RoundedPad1.0x1.5mm
LDO1: ME6211C33M5G-N; SOT-23-5_L3.0-W1.7-P0.95-LS2.8-BL; LCSC Part C82942
Q1: CJ2301 S1; SOT-23-3_L3.0-W1.7-P0.95-LS2.9-BR; LCSC Part C8547
Q2: SI2302_C2891732; SOT-23-3_L2.9-W1.3-P1.90-LS2.4-BR; LCSC Part C2891732
R3, R4, R6: 5.1k; R_0805_2012Metric_Pad1.20x1.40mm_HandSolder
R5: 10k; R_0805_2012Metric_Pad1.20x1.40mm_HandSolder
U2: GT-USB-7010ASV; USB-C-SMD_G-SWITCH_GT-USB-7010ASV; LCSC Part C2988369
U3: SL2.1A; SOP-16_L10.0-W3.9-P1.27-LS6.0-BL; LCSC Part C192893
USB1, USB2: KH-AF90DIP-112; USB-A-TH_USB-A-F-90; LCSC Part C503996
USB3: DNP; USB-A-TH_USB-A-F-90; LCSC Part C503996

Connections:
+3.3V: C15.1, LDO1.5 (VOUT); also elsewhere on the board
/MCU/GPIO_3: Q2.1 (G), R6.1; also elsewhere on the board
/MCU/USB_D+: U3.2 (DP4); also elsewhere on the board
/MCU/USB_D-: U3.1 (DM4); also elsewhere on the board
/USB/D+: U2.A6 (DP1), U2.B6 (DP2), U3.10 (DP)
/USB/D-: U2.A7 (DN1), U2.B7 (DN2), U3.9 (DM)
GND: C12.2, C13.1, C14.1, C15.2, C16.2, LDO1.2 (VSS), Q2.2 (S), R3.2, R4.2, R6.2, U2.1 (SHELL), U2.2 (SHELL), U2.3 (SHELL), U2.4 (SHELL), U2.A1B12 (GND), U2.B1A12 (GND), U3.12 (GND), U3.16 (XIN), USB1.0, USB1.4 (GND), USB2.0, USB2.4 (GND), USB3.0, USB3.4 (GND); also elsewhere on the board
unnamed: JP1.1 (A), Q1.3 (D)
unnamed: JP2.1 (A), Q1.2 (S), R5.2
unnamed: Q1.1 (G), Q2.3 (D), R5.1
unnamed: R4.1, U2.A5 (CC1)
unnamed: R3.1, U2.B5 (CC2)
unnamed: U3.7 (DM1), USB3.2 (D-)
unnamed: U3.5 (DM2), USB2.2 (D-)
unnamed: U3.3 (DM3), USB1.2 (D-)
unnamed: U3.8 (DP1), USB3.3 (D+)
unnamed: U3.6 (DP2), USB2.3 (D+)
unnamed: U3.4 (DP3), USB1.3 (D+)
unnamed: C13.2, U3.14 (VDD18)
unnamed: C14.2, U3.13 (VDD33)
VBUS: C12.1, C16.1, JP2.2 (B), LDO1.1 (VIN), LDO1.3 (CE), U2.A4B9 (VBUS), U2.B4A9 (VBUS), U3.11 (VDD5), USB2.1 (VCC), USB3.1 (VCC); also elsewhere on the board
Vdrive: JP1.2 (B), USB1.1 (VCC); also elsewhere on the board

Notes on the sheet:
USB Hub
LED_POWER
USB C
LDO

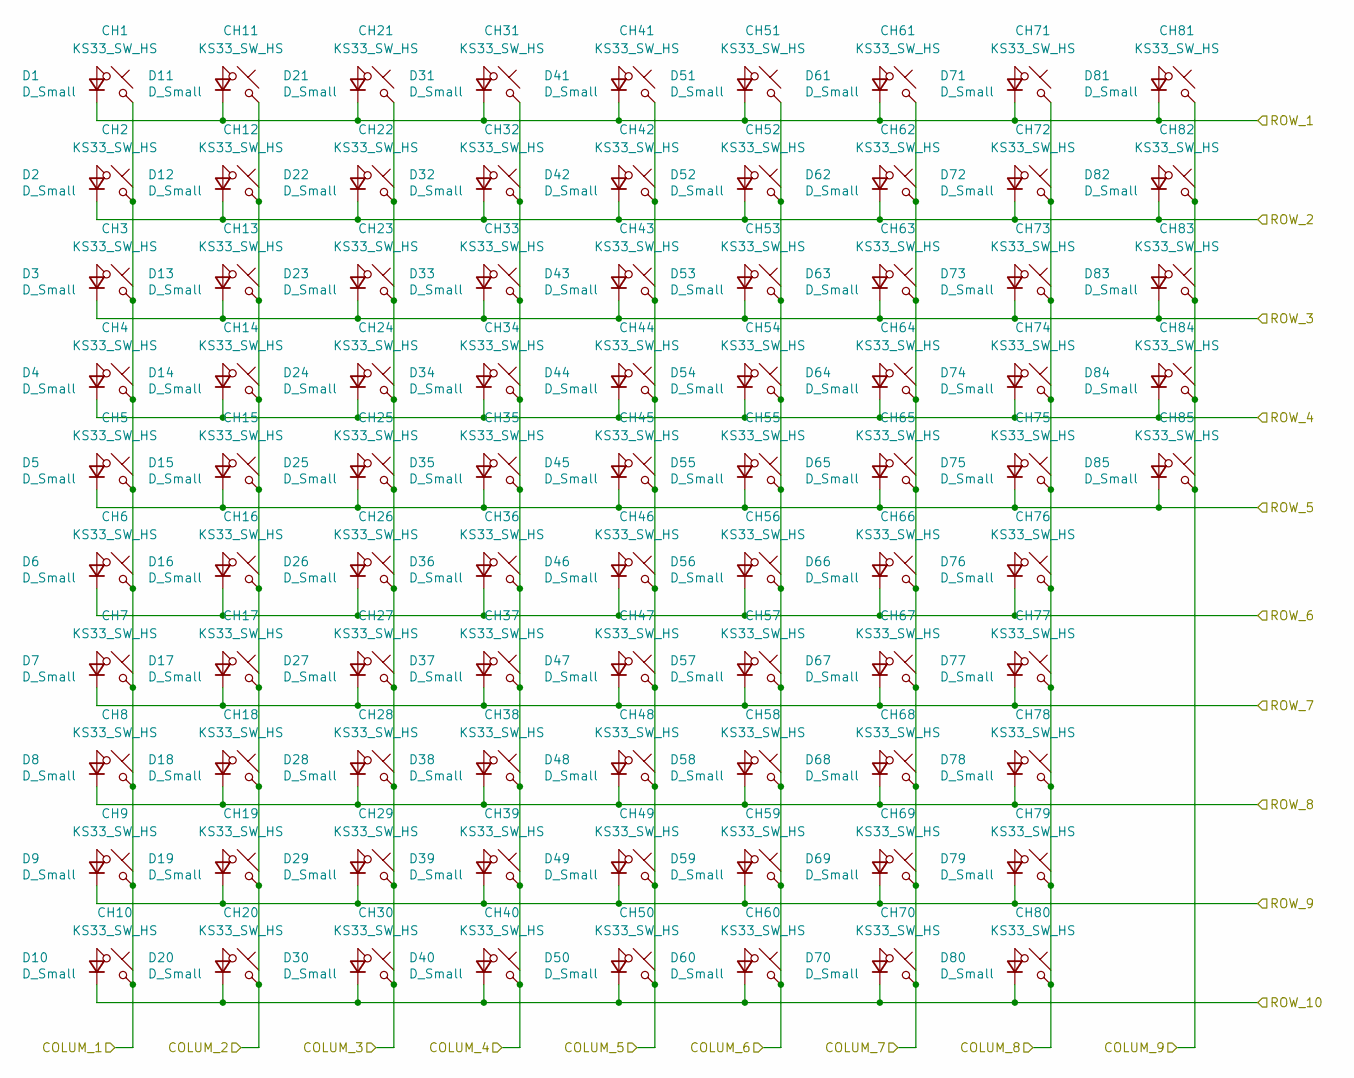
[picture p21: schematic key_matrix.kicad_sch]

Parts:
CH1, CH2, CH7, CH8, CH9, CH10, CH12, CH13, CH14, CH15, CH16, CH18, CH19, CH20, CH21, CH22, CH23, CH24, CH25, CH26, CH27, CH28, CH29, CH30, CH31, CH32, CH33, CH34, CH35, CH36, CH37, CH38, CH39, CH40, CH41, CH42, CH43, CH44, CH45, CH46, CH47, CH48, CH49, CH50, CH51, CH52, CH53, CH54, CH55, CH56, CH57, CH58, CH59, CH60, CH61, CH62, CH63, CH64, CH65, CH67, CH70, CH74, CH75, CH76, CH77, CH78, CH79, CH80, CH81, CH82, CH83, CH84, CH85: KS33_SW_HS; SW_KS33_HS_KS-2P02B01-02_HS_1u
CH3, CH68: KS33_SW_HS; SW_KS33_HS_KS-2P02B01-02_1.5u
CH4: KS33_SW_HS; SW_KS33_HS_KS-2P02B01-02_1.75u
CH5, CH6, CH11, CH17, CH66, CH69, CH71, CH72, CH73: KS33_SW_HS; SW_KS33_HS_KS-2P02B01-02_1.25u
D1, D2, D3, D4, D5, D6, D7, D8, D9, D10, D11, D12, D13, D14, D15, D16, D17, D18, D19, D20, D21, D22, D23, D24, D25, D26, D27, D28, D29, D30, D31, D32, D33, D34, D35, D36, D37, D38, D39, D40, D41, D42, D43, D44, D45, D46, D47, D48, D49, D50, D51, D52, D53, D54, D55, D56, D57, D58, D59, D60, D61, D62, D63, D64, D65, D66, D67, D68, D69, D70, D71, D72, D73, D74, D75, D76, D77, D78, D79, D80, D81, D82, D83, D84, D85: D_Small; D_DO-35_SOD27_P7.62mm_Horizontal

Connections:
/KeyMatrix/COLUM_1: CH1.2, CH2.2, CH3.2, CH4.2, CH5.2, CH6.2, CH7.2, CH8.2, CH9.2, CH10.2; also elsewhere on the board
/KeyMatrix/COLUM_2: CH11.2, CH12.2, CH13.2, CH14.2, CH15.2, CH16.2, CH17.2, CH18.2, CH19.2, CH20.2; also elsewhere on the board
/KeyMatrix/COLUM_3: CH21.2, CH22.2, CH23.2, CH24.2, CH25.2, CH26.2, CH27.2, CH28.2, CH29.2, CH30.2; also elsewhere on the board
/KeyMatrix/COLUM_4: CH31.2, CH32.2, CH33.2, CH34.2, CH35.2, CH36.2, CH37.2, CH38.2, CH39.2, CH40.2; also elsewhere on the board
/KeyMatrix/COLUM_5: CH41.2, CH42.2, CH43.2, CH44.2, CH45.2, CH46.2, CH47.2, CH48.2, CH49.2, CH50.2; also elsewhere on the board
/KeyMatrix/COLUM_6: CH51.2, CH52.2, CH53.2, CH54.2, CH55.2, CH56.2, CH57.2, CH58.2, CH59.2, CH60.2; also elsewhere on the board
/KeyMatrix/COLUM_7: CH61.2, CH62.2, CH63.2, CH64.2, CH65.2, CH66.2, CH67.2, CH68.2, CH69.2, CH70.2; also elsewhere on the board
/KeyMatrix/COLUM_8: CH71.2, CH72.2, CH73.2, CH74.2, CH75.2, CH76.2, CH77.2, CH78.2, CH79.2, CH80.2; also elsewhere on the board
/KeyMatrix/COLUM_9: CH81.2, CH82.2, CH83.2, CH84.2, CH85.2; also elsewhere on the board
/KeyMatrix/ROW_1: D1.1 (K), D11.1 (K), D21.1 (K), D31.1 (K), D41.1 (K), D51.1 (K), D61.1 (K), D71.1 (K), D81.1 (K); also elsewhere on the board
/KeyMatrix/ROW_2: D2.1 (K), D12.1 (K), D22.1 (K), D32.1 (K), D42.1 (K), D52.1 (K), D62.1 (K), D72.1 (K), D82.1 (K); also elsewhere on the board
/KeyMatrix/ROW_3: D3.1 (K), D13.1 (K), D23.1 (K), D33.1 (K), D43.1 (K), D53.1 (K), D63.1 (K), D73.1 (K), D83.1 (K); also elsewhere on the board
/KeyMatrix/ROW_4: D4.1 (K), D14.1 (K), D24.1 (K), D34.1 (K), D44.1 (K), D54.1 (K), D64.1 (K), D74.1 (K), D84.1 (K); also elsewhere on the board
/KeyMatrix/ROW_5: D5.1 (K), D15.1 (K), D25.1 (K), D35.1 (K), D45.1 (K), D55.1 (K), D65.1 (K), D75.1 (K), D85.1 (K); also elsewhere on the board
/KeyMatrix/ROW_6: D6.1 (K), D16.1 (K), D26.1 (K), D36.1 (K), D46.1 (K), D56.1 (K), D66.1 (K), D76.1 (K); also elsewhere on the board
/KeyMatrix/ROW_7: D7.1 (K), D17.1 (K), D27.1 (K), D37.1 (K), D47.1 (K), D57.1 (K), D67.1 (K), D77.1 (K); also elsewhere on the board
/KeyMatrix/ROW_8: D8.1 (K), D18.1 (K), D28.1 (K), D38.1 (K), D48.1 (K), D58.1 (K), D68.1 (K), D78.1 (K); also elsewhere on the board
/KeyMatrix/ROW_9: D9.1 (K), D19.1 (K), D29.1 (K), D39.1 (K), D49.1 (K), D59.1 (K), D69.1 (K), D79.1 (K); also elsewhere on the board
/KeyMatrix/ROW_10: D10.1 (K), D20.1 (K), D30.1 (K), D40.1 (K), D50.1 (K), D60.1 (K), D70.1 (K), D80.1 (K); also elsewhere on the board
unnamed: CH1.1, D1.2 (A)
unnamed: CH2.1, D2.2 (A)
unnamed: CH3.1, D3.2 (A)
unnamed: CH4.1, D4.2 (A)
unnamed: CH5.1, D5.2 (A)
unnamed: CH6.1, D6.2 (A)
unnamed: CH7.1, D7.2 (A)
unnamed: CH8.1, D8.2 (A)
unnamed: CH9.1, D9.2 (A)
unnamed: CH10.1, D10.2 (A)
unnamed: CH11.1, D11.2 (A)
unnamed: CH12.1, D12.2 (A)
unnamed: CH13.1, D13.2 (A)
unnamed: CH14.1, D14.2 (A)
unnamed: CH15.1, D15.2 (A)
unnamed: CH16.1, D16.2 (A)
unnamed: CH17.1, D17.2 (A)
unnamed: CH18.1, D18.2 (A)
unnamed: CH19.1, D19.2 (A)
unnamed: CH20.1, D20.2 (A)
unnamed: CH21.1, D21.2 (A)
unnamed: CH22.1, D22.2 (A)
unnamed: CH23.1, D23.2 (A)
unnamed: CH24.1, D24.2 (A)
unnamed: CH25.1, D25.2 (A)
unnamed: CH26.1, D26.2 (A)
unnamed: CH27.1, D27.2 (A)
unnamed: CH28.1, D28.2 (A)
unnamed: CH29.1, D29.2 (A)
unnamed: CH30.1, D30.2 (A)
unnamed: CH31.1, D31.2 (A)
unnamed: CH32.1, D32.2 (A)
unnamed: CH33.1, D33.2 (A)
unnamed: CH34.1, D34.2 (A)
unnamed: CH35.1, D35.2 (A)
unnamed: CH36.1, D36.2 (A)
unnamed: CH37.1, D37.2 (A)
unnamed: CH38.1, D38.2 (A)
unnamed: CH39.1, D39.2 (A)
unnamed: CH40.1, D40.2 (A)
unnamed: CH41.1, D41.2 (A)
unnamed: CH42.1, D42.2 (A)
unnamed: CH43.1, D43.2 (A)
unnamed: CH44.1, D44.2 (A)
unnamed: CH45.1, D45.2 (A)
unnamed: CH46.1, D46.2 (A)
unnamed: CH47.1, D47.2 (A)
unnamed: CH48.1, D48.2 (A)
unnamed: CH49.1, D49.2 (A)
unnamed: CH50.1, D50.2 (A)
unnamed: CH51.1, D51.2 (A)
unnamed: CH52.1, D52.2 (A)
unnamed: CH53.1, D53.2 (A)
unnamed: CH54.1, D54.2 (A)
unnamed: CH55.1, D55.2 (A)
unnamed: CH56.1, D56.2 (A)
unnamed: CH57.1, D57.2 (A)
unnamed: CH58.1, D58.2 (A)
unnamed: CH59.1, D59.2 (A)
unnamed: CH60.1, D60.2 (A)
unnamed: CH61.1, D61.2 (A)
unnamed: CH62.1, D62.2 (A)
unnamed: CH63.1, D63.2 (A)
unnamed: CH64.1, D64.2 (A)
unnamed: CH65.1, D65.2 (A)
unnamed: CH66.1, D66.2 (A)
unnamed: CH67.1, D67.2 (A)
unnamed: CH68.1, D68.2 (A)
unnamed: CH69.1, D69.2 (A)
unnamed: CH70.1, D70.2 (A)
unnamed: CH71.1, D71.2 (A)
unnamed: CH72.1, D72.2 (A)
unnamed: CH73.1, D73.2 (A)
unnamed: CH74.1, D74.2 (A)
unnamed: CH75.1, D75.2 (A)
unnamed: CH76.1, D76.2 (A)
unnamed: CH77.1, D77.2 (A)
unnamed: CH78.1, D78.2 (A)
unnamed: CH79.1, D79.2 (A)
unnamed: CH80.1, D80.2 (A)
unnamed: CH81.1, D81.2 (A)
unnamed: CH82.1, D82.2 (A)
unnamed: CH83.1, D83.2 (A)
unnamed: CH84.1, D84.2 (A)
unnamed: CH85.1, D85.2 (A)

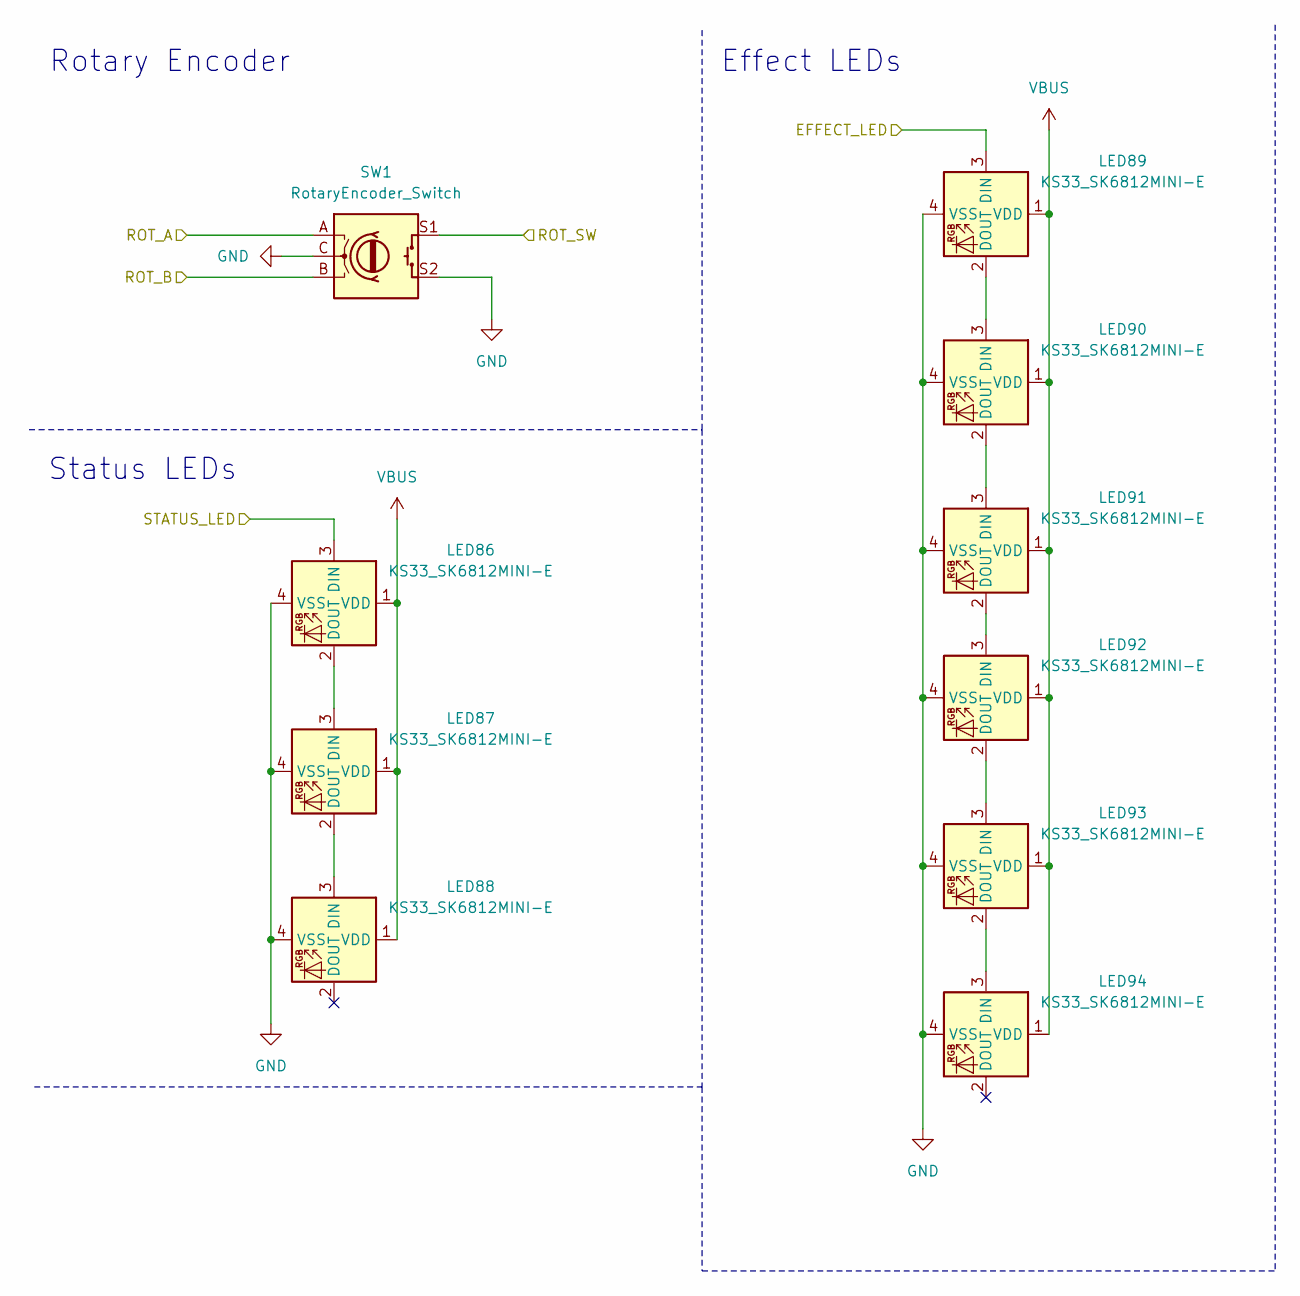
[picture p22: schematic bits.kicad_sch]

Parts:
LED86, LED87, LED88, LED89, LED90, LED91, LED92, LED93, LED94: KS33_SK6812MINI-E; LED_KS33_6028R
SW1: RotaryEncoder_Switch; RotaryEncoder_Alps_EC11E-Switch_Vertical_H20mm_CircularMoun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

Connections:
/Bits/EFFECT_LED: LED89.3 (DIN); also elsewhere on the board
/Bits/ROT_A: SW1.A; also elsewhere on the board
/Bits/ROT_B: SW1.B; also elsewhere on the board
/Bits/ROT_SW: SW1.S1; also elsewhere on the board
/Bits/STATUS_LED: LED86.3 (DIN); also elsewhere on the board
GND: LED86.4 (VSS), LED87.4 (VSS), LED88.4 (VSS), LED89.4 (VSS), LED90.4 (VSS), LED91.4 (VSS), LED92.4 (VSS), LED93.4 (VSS), LED94.4 (VSS), SW1.C, SW1.S2; also elsewhere on the board
unnamed: LED86.2 (DOUT), LED87.3 (DIN)
unnamed: LED87.2 (DOUT), LED88.3 (DIN)
unnamed: LED89.2 (DOUT), LED90.3 (DIN)
unnamed: LED90.2 (DOUT), LED91.3 (DIN)
unnamed: LED91.2 (DOUT), LED92.3 (DIN)
unnamed: LED92.2 (DOUT), LED93.3 (DIN)
unnamed: LED93.2 (DOUT), LED94.3 (DIN)
VBUS: LED86.1 (VDD), LED87.1 (VDD), LED88.1 (VDD), LED89.1 (VDD), LED90.1 (VDD), LED91.1 (VDD), LED92.1 (VDD), LED93.1 (VDD), LED94.1 (VDD); also elsewhere on the board

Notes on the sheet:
Status LEDs
Effect LEDs
Rotary Encoder

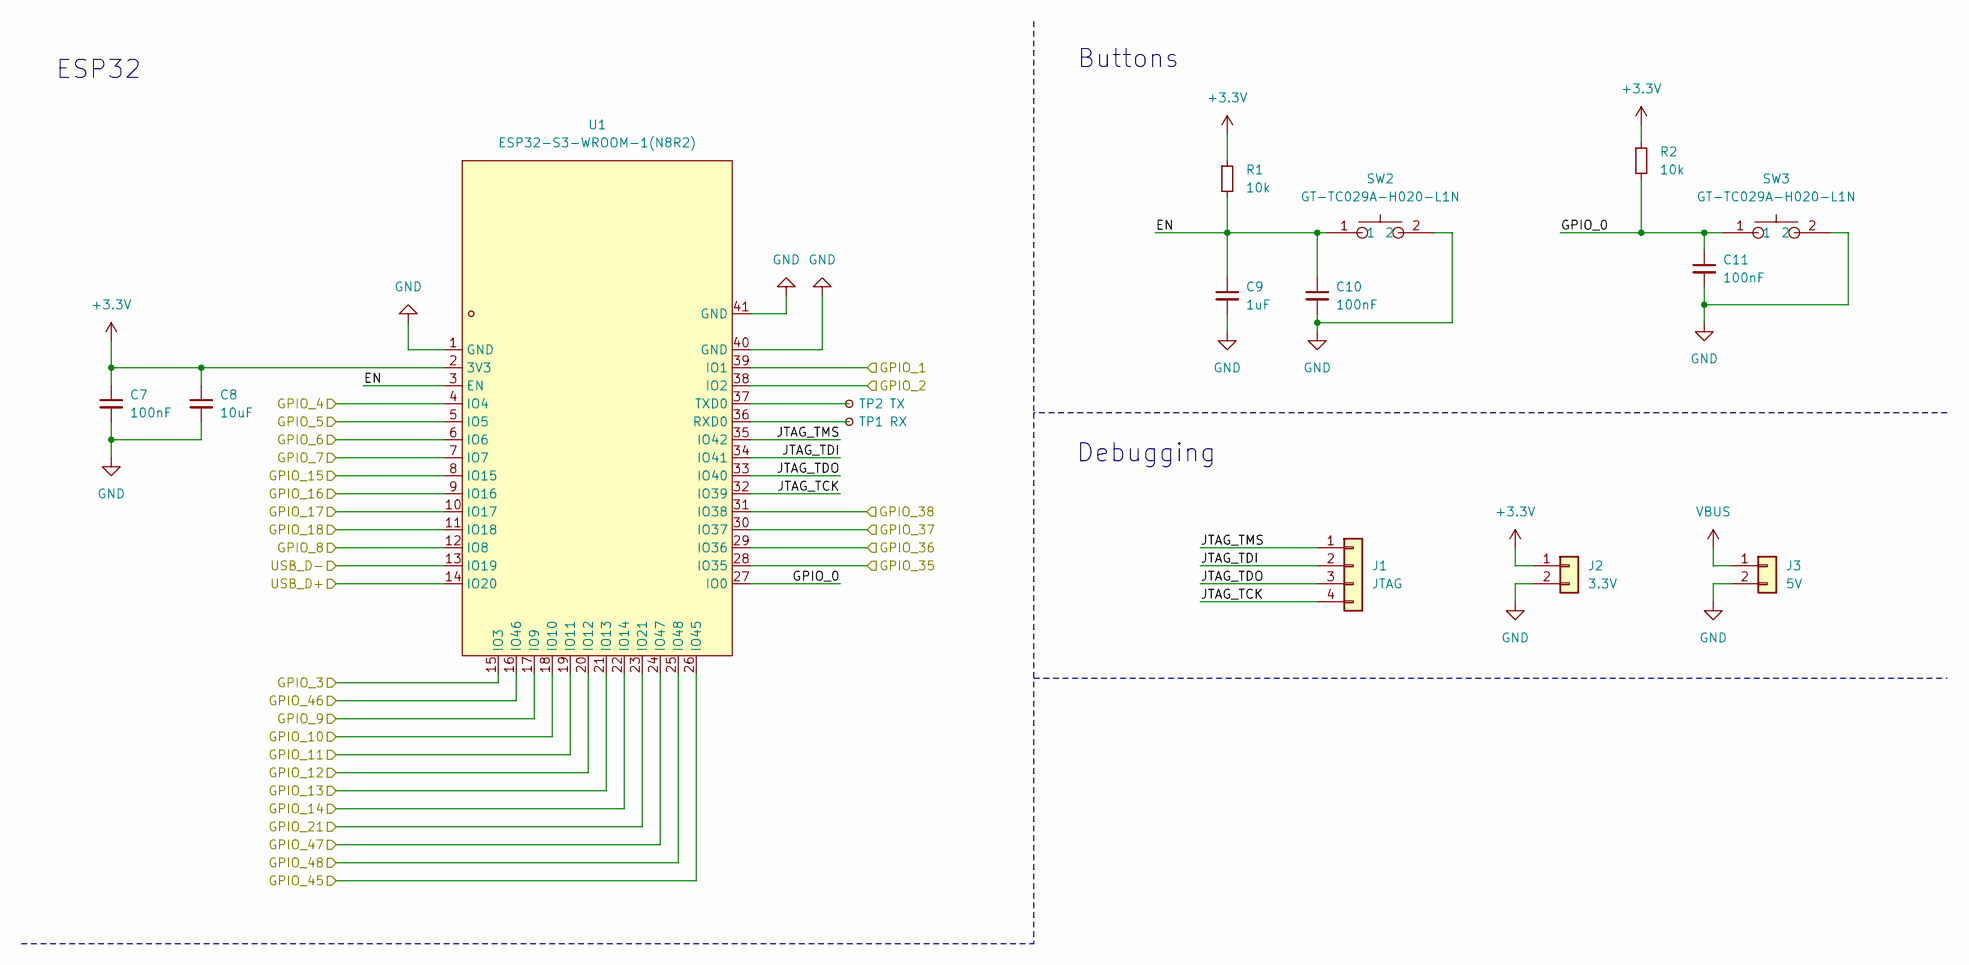
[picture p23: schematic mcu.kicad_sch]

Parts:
C7, C10, C11: 100nF; C_0805_2012Metric_Pad1.18x1.45mm_HandSolder
C8: 10uF; C_0805_2012Metric_Pad1.18x1.45mm_HandSolder
C9: 1uF; C_0805_2012Metric_Pad1.18x1.45mm_HandSolder
J1: JTAG; PinHeader_1x04_P1.00mm_Vertical
J2: 3.3V; PinHeader_1x02_P1.00mm_Vertical
J3: 5V; PinHeader_1x02_P1.00mm_Vertical
R1, R2: 10k; R_0805_2012Metric_Pad1.20x1.40mm_HandSolder
SW2, SW3: GT-TC029A-H020-L1N; SW-SMD_L3.9-W2.9-LS5.0; LCSC Part C778164
TP1: RX; TestPoint_Pad_D1.0mm
TP2: TX; TestPoint_Pad_D1.0mm
U1: ESP32-S3-WROOM-1(N8R2); WIRELM-SMD_ESP32-S3-WROOM-1; LCSC Part C2913204

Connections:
+3.3V: C7.1, C8.1, J2.1, R1.1, R2.1, U1.2 (3V3); also elsewhere on the board
/Bits/EFFECT_LED: U1.31 (IO38); also elsewhere on the board
/Bits/ROT_A: U1.26 (IO45); also elsewhere on the board
/Bits/ROT_B: U1.16 (IO46); also elsewhere on the board
/Bits/ROT_SW: U1.24 (IO47); also elsewhere on the board
/Bits/STATUS_LED: U1.25 (IO48); also elsewhere on the board
/KeyMatrix/COLUM_1: U1.4 (IO4); also elsewhere on the board
/KeyMatrix/COLUM_2: U1.5 (IO5); also elsewhere on the board
/KeyMatrix/COLUM_3: U1.6 (IO6); also elsewhere on the board
/KeyMatrix/COLUM_4: U1.7 (IO7); also elsewhere on the board
/KeyMatrix/COLUM_5: U1.12 (IO8); also elsewhere on the board
/KeyMatrix/COLUM_6: U1.17 (IO9); also elsewhere on the board
/KeyMatrix/COLUM_7: U1.18 (IO10); also elsewhere on the board
/KeyMatrix/COLUM_8: U1.19 (IO11); also elsewhere on the board
/KeyMatrix/COLUM_9: U1.20 (IO12); also elsewhere on the board
/KeyMatrix/ROW_1: U1.21 (IO13); also elsewhere on the board
/KeyMatrix/ROW_2: U1.22 (IO14); also elsewhere on the board
/KeyMatrix/ROW_3: U1.8 (IO15); also elsewhere on the board
/KeyMatrix/ROW_4: U1.9 (IO16); also elsewhere on the board
/KeyMatrix/ROW_5: U1.10 (IO17); also elsewhere on the board
/KeyMatrix/ROW_6: U1.11 (IO18); also elsewhere on the board
/KeyMatrix/ROW_7: U1.23 (IO21); also elsewhere on the board
/KeyMatrix/ROW_8: U1.28 (IO35); also elsewhere on the board
/KeyMatrix/ROW_9: U1.29 (IO36); also elsewhere on the board
/KeyMatrix/ROW_10: U1.30 (IO37); also elsewhere on the board
/LEDs/DIN: U1.39 (IO1); also elsewhere on the board
/MCU/EN: C9.1, C10.1, R1.2, SW2.1, U1.3 (EN)
/MCU/GPIO_0: C11.1, R2.2, SW3.1, U1.27 (IO0)
/MCU/GPIO_2: U1.38 (IO2)
/MCU/GPIO_3: U1.15 (IO3); also elsewhere on the board
/MCU/JTAG_TCK: J1.4, U1.32 (IO39)
/MCU/JTAG_TDI: J1.2, U1.34 (IO41)
/MCU/JTAG_TDO: J1.3, U1.33 (IO40)
/MCU/JTAG_TMS: J1.1, U1.35 (IO42)
/MCU/USB_D+: U1.14 (IO20); also elsewhere on the board
/MCU/USB_D-: U1.13 (IO19); also elsewhere on the board
GND: C7.2, C8.2, C9.2, C10.2, C11.2, J2.2, J3.2, SW2.2, SW3.2, U1.1 (GND), U1.40 (GND), U1.41 (GND); also elsewhere on the board
unnamed: TP1.1, U1.36 (RXD0)
unnamed: TP2.1, U1.37 (TXD0)
VBUS: J3.1; also elsewhere on the board

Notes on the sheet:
Buttons
Debugging
ESP32

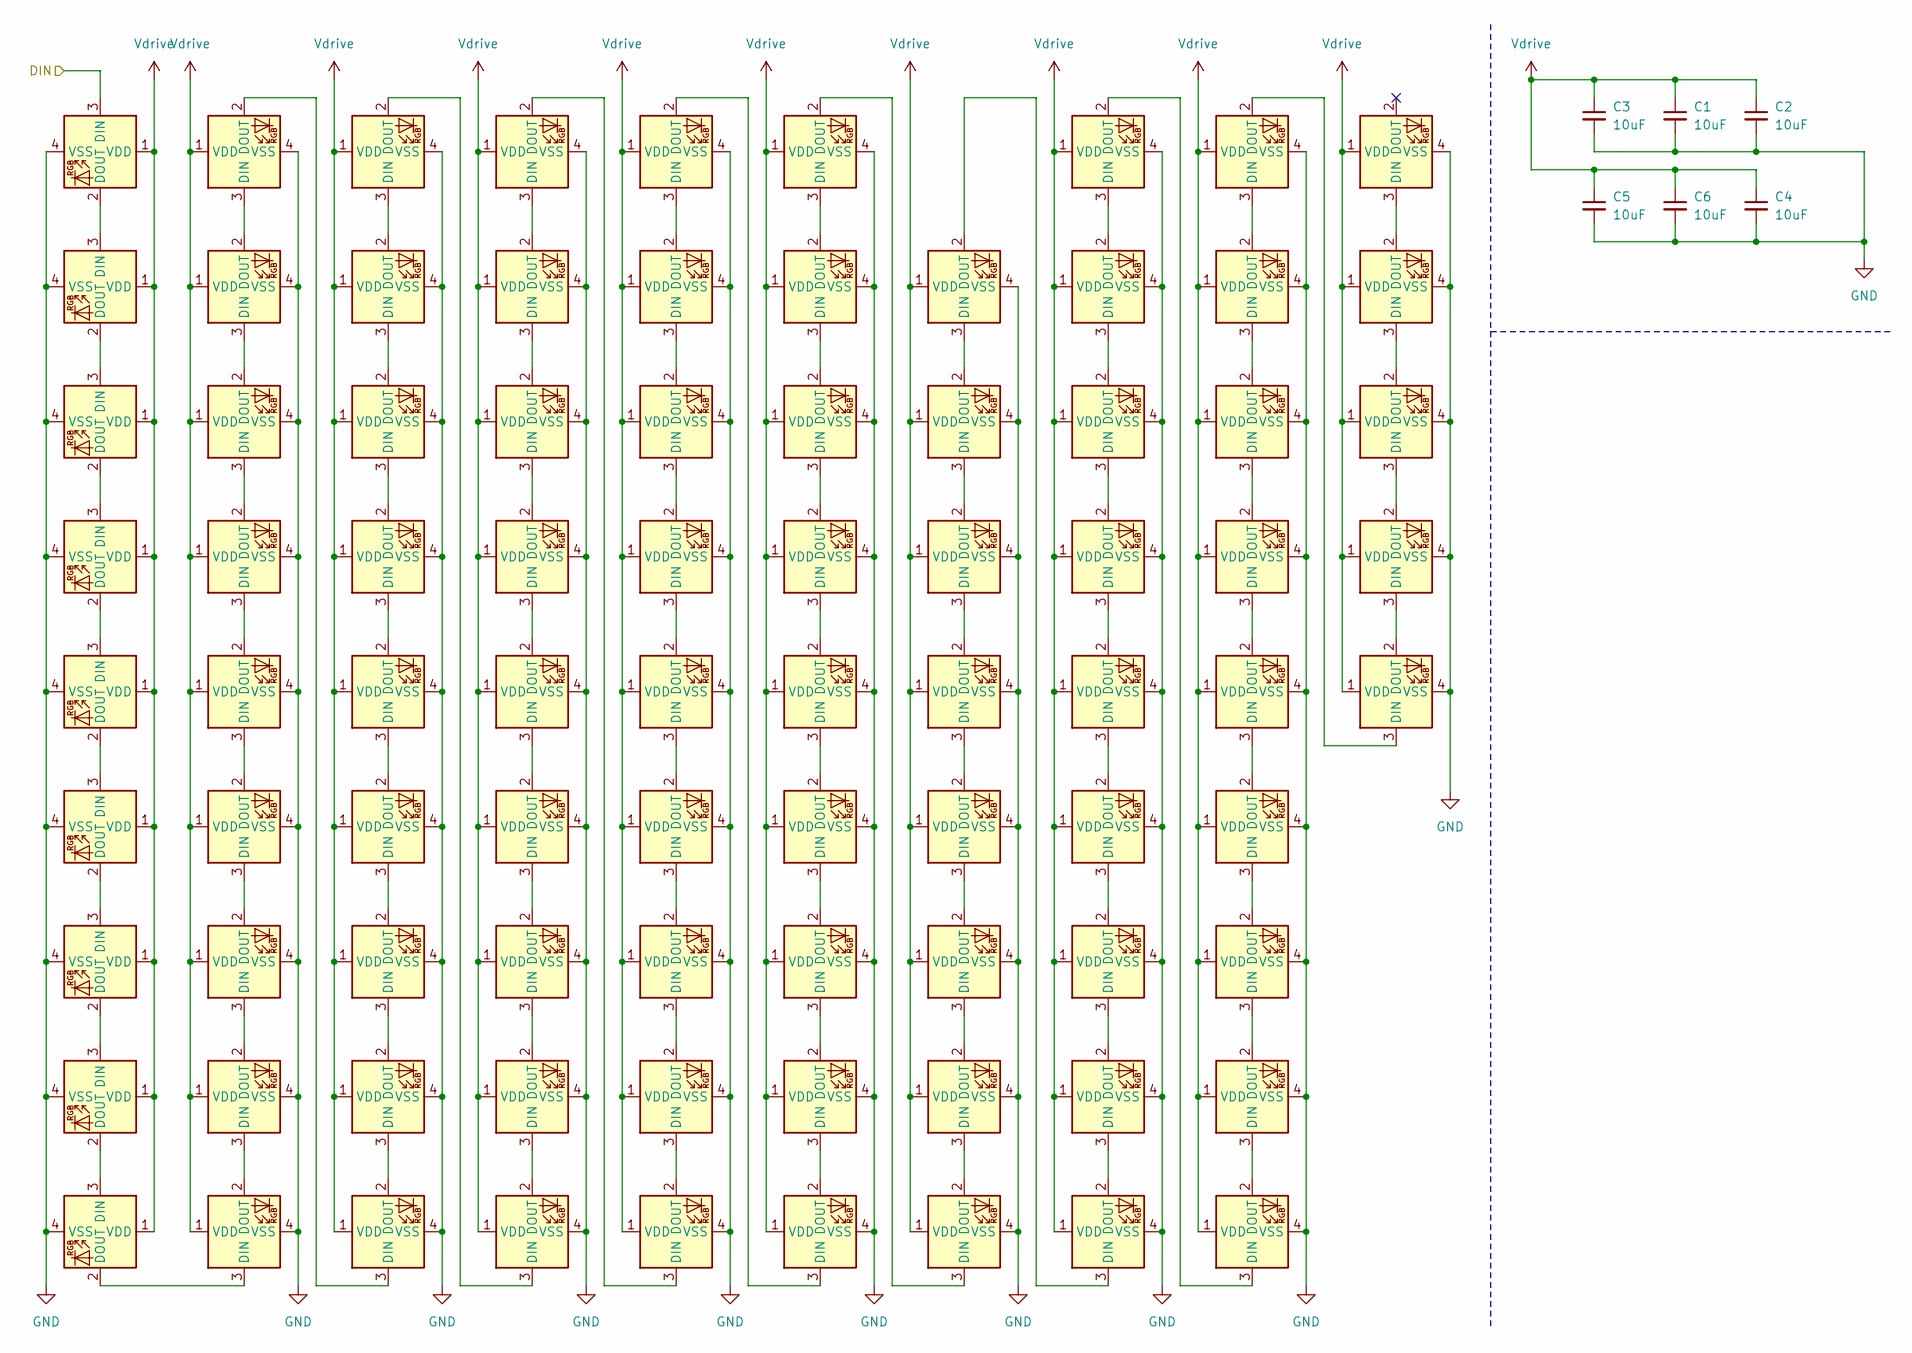
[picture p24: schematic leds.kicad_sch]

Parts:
C1, C2, C3, C4, C5, C6: 10uF; C_0805_2012Metric_Pad1.18x1.45mm_HandSolder
LED1, LED2, LED3, LED4, LED5, LED6, LED7, LED8, LED9, LED10, LED11, LED12, LED13, LED14, LED15, LED16, LED17, LED18, LED19, LED20, LED21, LED22, LED23, LED24, LED25, LED26, LED27, LED28, LED29, LED30, LED31, LED32, LED33, LED34, LED35, LED36, LED37, LED38, LED39, LED40, LED41, LED42, LED43, LED44, LED45, LED46, LED47, LED48, LED49, LED50, LED51, LED52, LED53, LED54, LED55, LED56, LED57, LED58, LED59, LED60, LED61, LED62, LED63, LED64, LED65, LED66, LED67, LED68, LED69, LED70, LED71, LED72, LED73, LED74, LED75, LED76, LED77, LED78, LED79, LED80, LED81, LED82, LED83, LED84, LED85: KS33_SK6812MINI-E; LED_KS33_6028R

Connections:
/LEDs/DIN: LED15.3 (DIN); also elsewhere on the board
GND: C1.2, C2.2, C3.2, C4.2, C5.2, C6.2, LED1.4 (VSS), LED2.4 (VSS), LED3.4 (VSS), LED4.4 (VSS), LED5.4 (VSS), LED6.4 (VSS), LED7.4 (VSS), LED8.4 (VSS), LED9.4 (VSS), LED10.4 (VSS), LED11.4 (VSS), LED12.4 (VSS), LED13.4 (VSS), LED14.4 (VSS), LED15.4 (VSS), LED16.4 (VSS), LED17.4 (VSS), LED18.4 (VSS), LED19.4 (VSS), LED20.4 (VSS), LED21.4 (VSS), LED22.4 (VSS), LED23.4 (VSS), LED24.4 (VSS), LED25.4 (VSS), LED26.4 (VSS), LED27.4 (VSS), LED28.4 (VSS), LED29.4 (VSS), LED30.4 (VSS), LED31.4 (VSS), LED32.4 (VSS), LED33.4 (VSS), LED34.4 (VSS), LED35.4 (VSS), LED36.4 (VSS), LED37.4 (VSS), LED38.4 (VSS), LED39.4 (VSS), LED40.4 (VSS), LED41.4 (VSS), LED42.4 (VSS), LED43.4 (VSS), LED44.4 (VSS), LED45.4 (VSS), LED46.4 (VSS), LED47.4 (VSS), LED48.4 (VSS), LED49.4 (VSS), LED50.4 (VSS), LED51.4 (VSS), LED52.4 (VSS), LED53.4 (VSS), LED54.4 (VSS), LED55.4 (VSS), LED56.4 (VSS), LED57.4 (VSS), LED58.4 (VSS), LED59.4 (VSS), LED60.4 (VSS), LED61.4 (VSS), LED62.4 (VSS), LED63.4 (VSS), LED64.4 (VSS), LED65.4 (VSS), LED66.4 (VSS), LED67.4 (VSS), LED68.4 (VSS), LED69.4 (VSS), LED70.4 (VSS), LED71.4 (VSS), LED72.4 (VSS), LED73.4 (VSS), LED74.4 (VSS), LED75.4 (VSS), LED76.4 (VSS), LED77.4 (VSS), LED78.4 (VSS), LED79.4 (VSS), LED80.4 (VSS), LED81.4 (VSS), LED82.4 (VSS), LED83.4 (VSS), LED84.4 (VSS), LED85.4 (VSS); also elsewhere on the board
unnamed: LED1.3 (DIN), LED18.2 (DOUT)
unnamed: LED1.2 (DOUT), LED2.3 (DIN)
unnamed: LED2.2 (DOUT), LED3.3 (DIN)
unnamed: LED3.2 (DOUT), LED4.3 (DIN)
unnamed: LED4.2 (DOUT), LED5.3 (DIN)
unnamed: LED5.2 (DOUT), LED6.3 (DIN)
unnamed: LED6.2 (DOUT), LED7.3 (DIN)
unnamed: LED7.2 (DOUT), LED8.3 (DIN)
unnamed: LED8.2 (DOUT), LED9.3 (DIN)
unnamed: LED10.3 (DIN), LED11.2 (DOUT)
unnamed: LED10.2 (DOUT), LED27.3 (DIN)
unnamed: LED11.3 (DIN), LED12.2 (DOUT)
unnamed: LED12.3 (DIN), LED13.2 (DOUT)
unnamed: LED13.3 (DIN), LED14.2 (DOUT)
unnamed: LED9.2 (DOUT), LED14.3 (DIN)
unnamed: LED15.2 (DOUT), LED16.3 (DIN)
unnamed: LED16.2 (DOUT), LED17.3 (DIN)
unnamed: LED17.2 (DOUT), LED18.3 (DIN)
unnamed: LED19.3 (DIN), LED20.2 (DOUT)
unnamed: LED19.2 (DOUT), LED36.3 (DIN)
unnamed: LED20.3 (DIN), LED21.2 (DOUT)
unnamed: LED21.3 (DIN), LED22.2 (DOUT)
unnamed: LED22.3 (DIN), LED23.2 (DOUT)
unnamed: LED23.3 (DIN), LED24.2 (DOUT)
unnamed: LED24.3 (DIN), LED25.2 (DOUT)
unnamed: LED25.3 (DIN), LED26.2 (DOUT)
unnamed: LED26.3 (DIN), LED27.2 (DOUT)
unnamed: LED28.3 (DIN), LED29.2 (DOUT)
unnamed: LED28.2 (DOUT), LED45.3 (DIN)
unnamed: LED29.3 (DIN), LED30.2 (DOUT)
unnamed: LED30.3 (DIN), LED31.2 (DOUT)
unnamed: LED31.3 (DIN), LED32.2 (DOUT)
unnamed: LED32.3 (DIN), LED33.2 (DOUT)
unnamed: LED33.3 (DIN), LED34.2 (DOUT)
unnamed: LED34.3 (DIN), LED35.2 (DOUT)
unnamed: LED35.3 (DIN), LED36.2 (DOUT)
unnamed: LED37.3 (DIN), LED38.2 (DOUT)
unnamed: LED37.2 (DOUT), LED54.3 (DIN)
unnamed: LED38.3 (DIN), LED39.2 (DOUT)
unnamed: LED39.3 (DIN), LED40.2 (DOUT)
unnamed: LED40.3 (DIN), LED41.2 (DOUT)
unnamed: LED41.3 (DIN), LED42.2 (DOUT)
unnamed: LED42.3 (DIN), LED43.2 (DOUT)
unnamed: LED43.3 (DIN), LED44.2 (DOUT)
unnamed: LED44.3 (DIN), LED45.2 (DOUT)
unnamed: LED46.3 (DIN), LED47.2 (DOUT)
unnamed: LED46.2 (DOUT), LED63.3 (DIN)
unnamed: LED47.3 (DIN), LED48.2 (DOUT)
unnamed: LED48.3 (DIN), LED49.2 (DOUT)
unnamed: LED49.3 (DIN), LED50.2 (DOUT)
unnamed: LED50.3 (DIN), LED51.2 (DOUT)
unnamed: LED51.3 (DIN), LED52.2 (DOUT)
unnamed: LED52.3 (DIN), LED53.2 (DOUT)
unnamed: LED53.3 (DIN), LED54.2 (DOUT)
unnamed: LED55.3 (DIN), LED82.2 (DOUT)
unnamed: LED56.3 (DIN), LED57.2 (DOUT)
unnamed: LED56.2 (DOUT), LED72.3 (DIN)
unnamed: LED57.3 (DIN), LED58.2 (DOUT)
unnamed: LED58.3 (DIN), LED59.2 (DOUT)
unnamed: LED59.3 (DIN), LED60.2 (DOUT)
unnamed: LED60.3 (DIN), LED61.2 (DOUT)
unnamed: LED61.3 (DIN), LED62.2 (DOUT)
unnamed: LED62.3 (DIN), LED63.2 (DOUT)
unnamed: LED64.3 (DIN), LED65.2 (DOUT)
unnamed: LED64.2 (DOUT), LED81.3 (DIN)
unnamed: LED65.3 (DIN), LED66.2 (DOUT)
unnamed: LED66.3 (DIN), LED67.2 (DOUT)
unnamed: LED67.3 (DIN), LED68.2 (DOUT)
unnamed: LED68.3 (DIN), LED69.2 (DOUT)
unnamed: LED69.3 (DIN), LED70.2 (DOUT)
unnamed: LED70.3 (DIN), LED71.2 (DOUT)
unnamed: LED71.3 (DIN), LED72.2 (DOUT)
unnamed: LED73.3 (DIN), LED74.2 (DOUT)
unnamed: LED73.2 (DOUT), LED85.3 (DIN)
unnamed: LED74.3 (DIN), LED75.2 (DOUT)
unnamed: LED75.3 (DIN), LED76.2 (DOUT)
unnamed: LED76.3 (DIN), LED77.2 (DOUT)
unnamed: LED77.3 (DIN), LED78.2 (DOUT)
unnamed: LED78.3 (DIN), LED79.2 (DOUT)
unnamed: LED79.3 (DIN), LED80.2 (DOUT)
unnamed: LED80.3 (DIN), LED81.2 (DOUT)
unnamed: LED82.3 (DIN), LED83.2 (DOUT)
unnamed: LED83.3 (DIN), LED84.2 (DOUT)
unnamed: LED84.3 (DIN), LED85.2 (DOUT)
Vdrive: C1.1, C2.1, C3.1, C4.1, C5.1, C6.1, LED1.1 (VDD), LED2.1 (VDD), LED3.1 (VDD), LED4.1 (VDD), LED5.1 (VDD), LED6.1 (VDD), LED7.1 (VDD), LED8.1 (VDD), LED9.1 (VDD), LED10.1 (VDD), LED11.1 (VDD), LED12.1 (VDD), LED13.1 (VDD), LED14.1 (VDD), LED15.1 (VDD), LED16.1 (VDD), LED17.1 (VDD), LED18.1 (VDD), LED19.1 (VDD), LED20.1 (VDD), LED21.1 (VDD), LED22.1 (VDD), LED23.1 (VDD), LED24.1 (VDD), LED25.1 (VDD), LED26.1 (VDD), LED27.1 (VDD), LED28.1 (VDD), LED29.1 (VDD), LED30.1 (VDD), LED31.1 (VDD), LED32.1 (VDD), LED33.1 (VDD), LED34.1 (VDD), LED35.1 (VDD), LED36.1 (VDD), LED37.1 (VDD), LED38.1 (VDD), LED39.1 (VDD), LED40.1 (VDD), LED41.1 (VDD), LED42.1 (VDD), LED43.1 (VDD), LED44.1 (VDD), LED45.1 (VDD), LED46.1 (VDD), LED47.1 (VDD), LED48.1 (VDD), LED49.1 (VDD), LED50.1 (VDD), LED51.1 (VDD), LED52.1 (VDD), LED53.1 (VDD), LED54.1 (VDD), LED55.1 (VDD), LED56.1 (VDD), LED57.1 (VDD), LED58.1 (VDD), LED59.1 (VDD), LED60.1 (VDD), LED61.1 (VDD), LED62.1 (VDD), LED63.1 (VDD), LED64.1 (VDD), LED65.1 (VDD), LED66.1 (VDD), LED67.1 (VDD), LED68.1 (VDD), LED69.1 (VDD), LED70.1 (VDD), LED71.1 (VDD), LED72.1 (VDD), LED73.1 (VDD), LED74.1 (VDD), LED75.1 (VDD), LED76.1 (VDD), LED77.1 (VDD), LED78.1 (VDD), LED79.1 (VDD), LED80.1 (VDD), LED81.1 (VDD), LED82.1 (VDD), LED83.1 (VDD), LED84.1 (VDD), LED85.1 (VDD); also elsewhere on the board

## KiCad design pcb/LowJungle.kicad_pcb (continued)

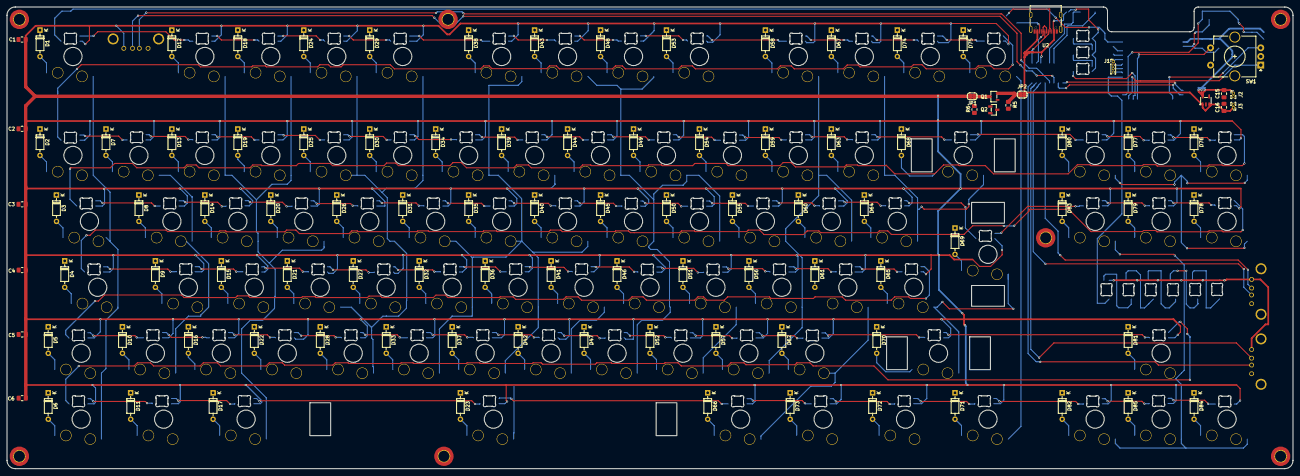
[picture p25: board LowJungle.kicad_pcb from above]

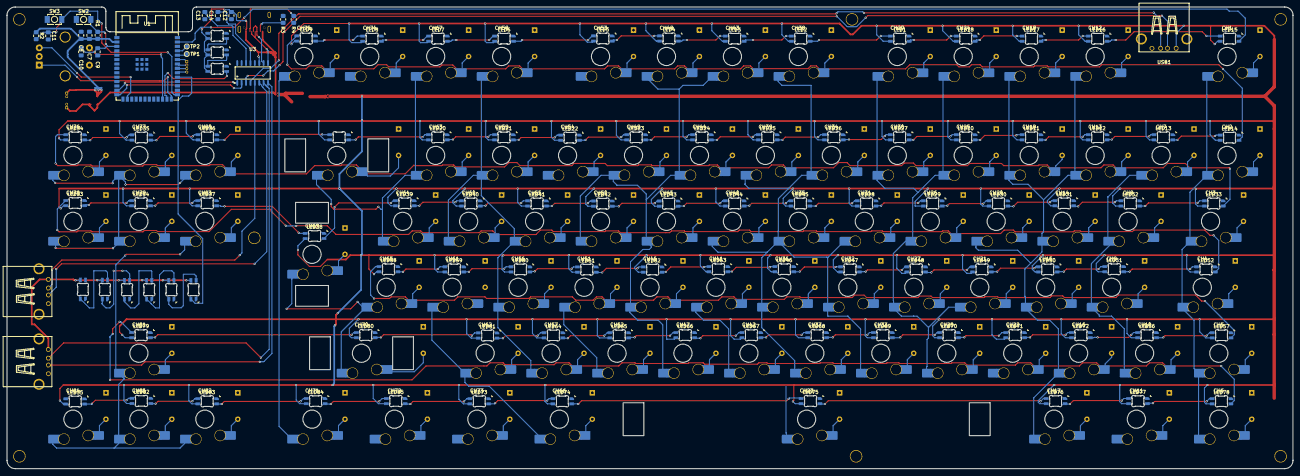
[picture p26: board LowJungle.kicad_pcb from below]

Board: 2 copper layers, 371.5 x 133.4 mm, 312 parts (115 on the bottom side), 231 nets.

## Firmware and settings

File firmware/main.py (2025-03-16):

# Note: Currently the firmware is only for testing the hardware. Pins are correct
import board
import busio

from kmk.kmk_keyboard import KMKKeyboard
from kmk.keys import KC
from kmk.scanners import DiodeOrientation

from kmk.extensions.RGB import RGB

from kmk.modules.encoder import EncoderHandler


# Inits
keyboard = KMKKeyboard()


# Modules
encoder_handler = EncoderHandler()

keyboard.modules = [encoder_handler]


# Extension - RGB
rgb = RGB(pixel_pin=board.GP1, num_pixels=85)
keyboard.extensions.append(rgb)


# Matrix config
keyboard.col_pins = (
    board.GP4,
    board.GP5,
    board.GP6,
    board.GP7,
    board.GP8,
    board.GP9,
    board.GP10,
    board.GP11,
    board.GP12,
)
keyboard.row_pins = (
    board.GP13,
    board.GP14,
    board.GP15,
    board.GP16,
    board.GP17,
    board.GP18,
    board.GP21,
    board.GP35,
    board.GP36,
    board.GP37,
)
keyboard.diode_orientation = DiodeOrientation.COL2ROW


# Encoder config
encoder_handler.pins = ((board.GP45, board.GP46, board.GP47, False),)


# TODO: Add status and effect leds: Needs to be handled separately
# TODO: Fillin keymap - research special keys with KMK, MacOS support, different languages

# Keymap
keyboard.keymap = []

encoder_handler.map = [
    ((KC.UP, KC.DOWN, KC.MUTE),),
]


# Loop
if __name__ == "__main__":
    keyboard.go()

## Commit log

2025-03-14 Created keymatrix
    [LowJungle.kicad_pcb, key_matrix.kicad_sch, leds.kicad_sch]
2025-03-15 Move all hot swap socket to flipping right side
    [LowJungle.kicad_pcb]
2025-03-15 Added stabilizers
    [LowJungle.kicad_pcb]
2025-03-15 Finished schematic
    [LowJungle.kicad_pcb, LowJungle.kicad_sch, bits.kicad_sch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]
2025-03-15 Started routing
    [LowJungle.kicad_pcb, LowJungle.kicad_sch, bom.csv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]
2025-03-15 Finished PCB!!
    [positions.csv]
2025-03-16 Finished PCB, added BOM, improved docs
2025-03-16 added more mounting holes
    [LowJungle.kicad_sch]
2025-03-16 Improved silkscreen, added foam to bom
2025-03-16 Added case
    [LowJungle-Edge_Cuts.dxf, LowJungle.step]
2025-03-18 Improved case! Added fasteners section to documentation
    [LowJungle-Backplate-V2.stl, LowJungle-Bottom-V2.stl, LowJungle-Bumper-Top-V2.stl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]
